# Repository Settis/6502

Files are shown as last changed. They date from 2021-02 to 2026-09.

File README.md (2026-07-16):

This was started as a self-educational project.
To understand how computer works I decided to create one.
The main rule here is that I should understand each bit, each connection.
I try to build it from scratch as much as possible.

I've started with a 6502 compatible CPU in Logisim [avaialbe here](/logisim/README.md).

Currently, I'm trying to build the real one around 65c816 CPU. 
As an example of how it looks you can see it working with three character displays running Wozmon:
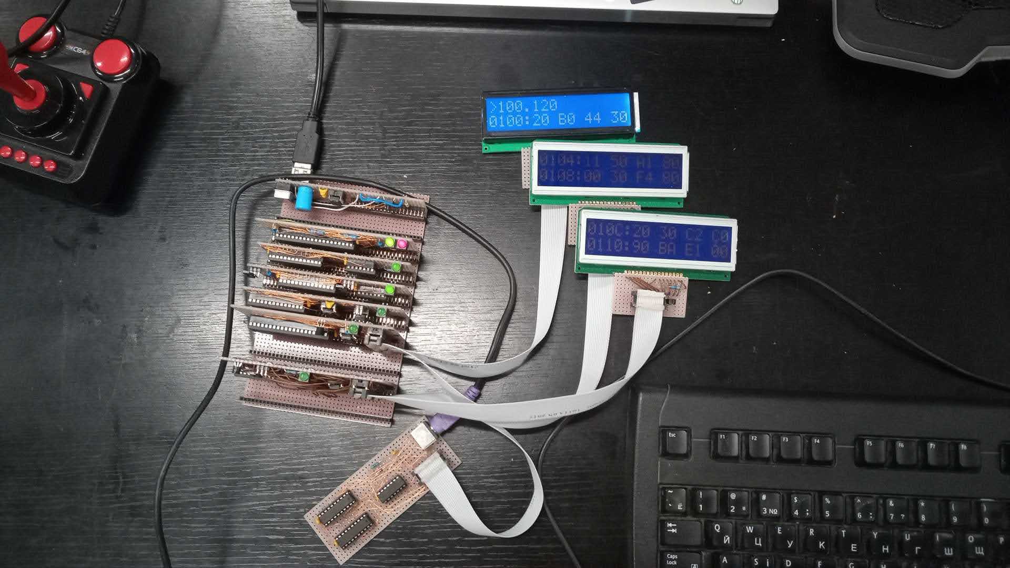
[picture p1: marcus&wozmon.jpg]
photo of 6502 computer running Wozmon


Finally I'm able to connect all peripherals at once:
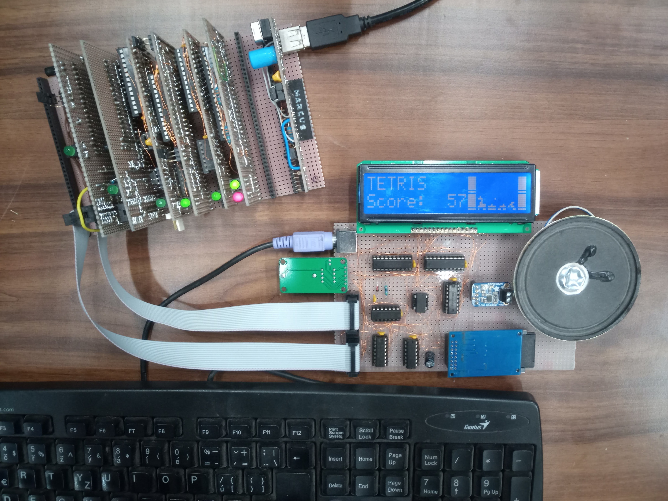
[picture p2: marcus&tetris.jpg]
photo of 6502 computer running Tetris


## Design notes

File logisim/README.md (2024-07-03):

This computer has a tty and graphical display. 
You can see how "comp.circ" looks like opened in Logisim:
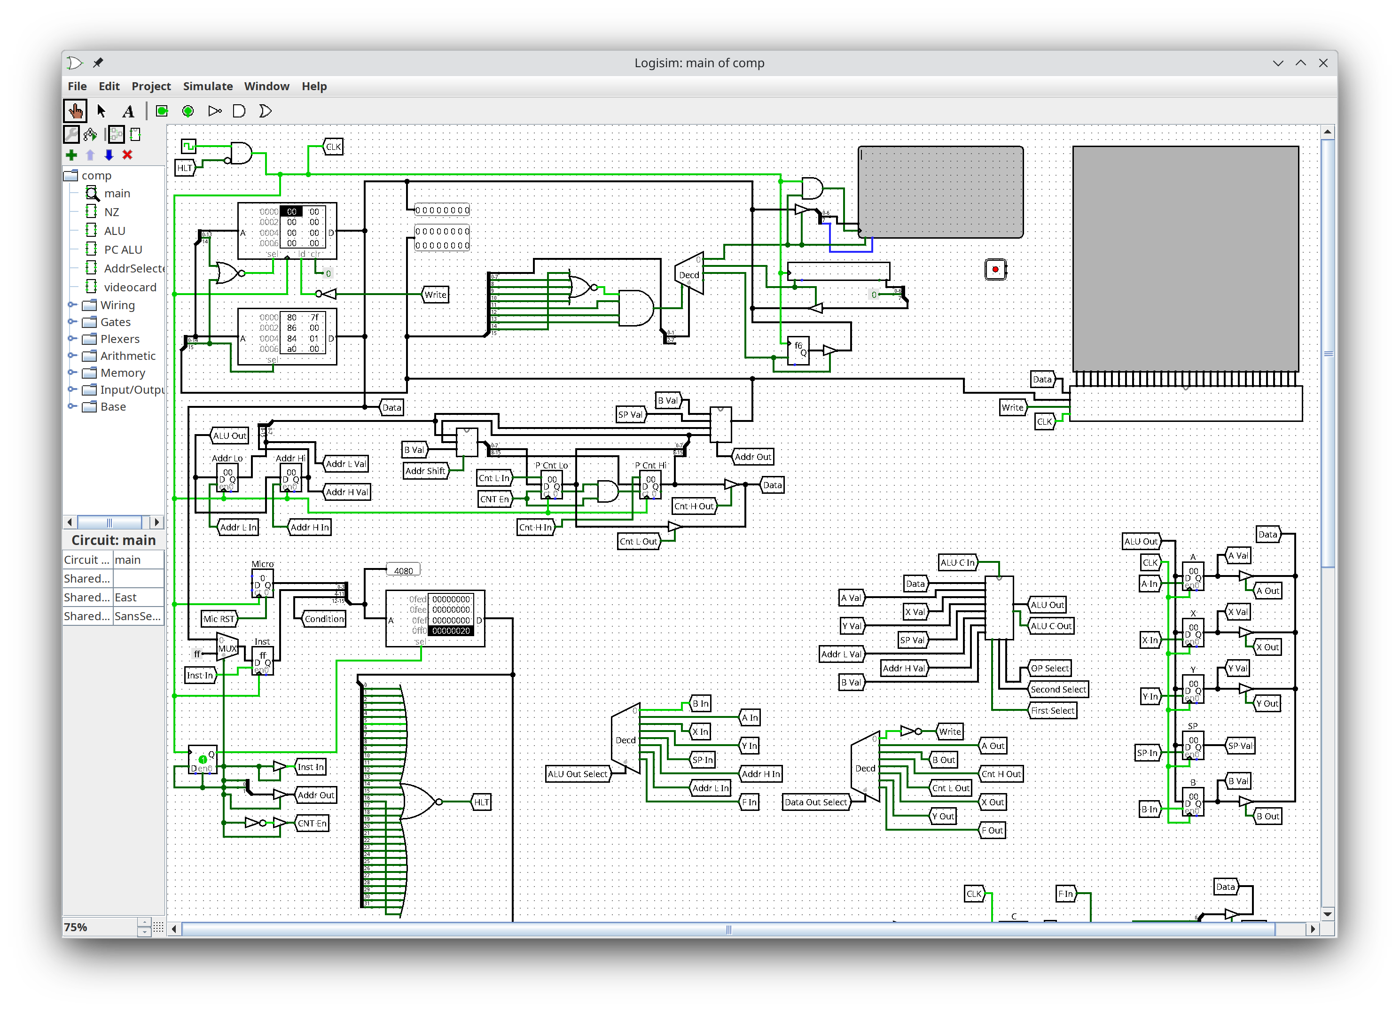
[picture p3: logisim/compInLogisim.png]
Logisim circuit


The microcode for the CPU was generated from "tools/microcodeSpec.yaml" by "tools/microcodeGen.py".

PNG images were converted by "tools/imageConvert.py".

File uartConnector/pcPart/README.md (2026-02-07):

# Communication with 6502 via UART
Happy coding!

## Local build & install
### Build package
> python3 -m pip install --upgrade build
> 
> python3 -m build
### Install package
> pip install 6502arch_uart-0.0.2-py3-none-any.whl

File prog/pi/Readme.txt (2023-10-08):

GPT предложил выводить бинарник при помощи `hexdump -v -e '/1 "%d "'`
Таким образом он выведет: 3 1 4 1 5 9 2 ...

```
const N = 1000;
const LEN = Math.floor((10 * N) / 3) + 1;

const a = Array(LEN);
let previousDigit = 2;
let nineCount = 0;

for (let i = 0; i < LEN; i++) {
  a[i] = 2;
}

let printed = 0;
while (printed < N) {
  // multiply each digit by 10
  // normalize representation
  //   each digit should be in range 0..2i, so carry extra rank to higher digit
  let carry = 0;
  for (let i = LEN - 1, numerator = (2 * LEN - 1); i > 0; i--, numerator -= 2) {
    const x = a[i] * 10 + carry;
    a[i] = x % numerator
    carry = Math.floor(x / numerator) * i;
  }

  // latest carry would be integer part of current number 
  //   and sequental digit of Pi
  const digitFromCarry = Math.floor(carry / 10);
  const nextDigit = carry % 10;

  // if current digit is 9, then we can't decide if we would have cascade carry
  if (nextDigit === 9) {
    nineCount++;
    continue;
  }

  // print previous digit, because now we knows if current digit is more than 10
  const currentDigit = previousDigit + digitFromCarry;
  process.stdout.write(currentDigit.toString());
  printed++;

  // if previous digit is followed by 9s, then print them 
  //   or 0s, if we have cascade carry
  for (let i = 0; i < nineCount; i++) {
    process.stdout.write((digitFromCarry === 0 ? 9 : 0).toString());
    printed++;
  }
  nineCount = 0;

  previousDigit = nextDigit;
}
```

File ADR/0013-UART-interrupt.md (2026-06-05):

# UART chip bug workaround

Status: accepted

## Context

Swapping DTR and RTS lines reveals another hardware bug.
When I setup that the data terminal is not ready, the terminal transfers bytes, and receive bytes.
Unfortunately, it stopped generating interrupts.

## Decision

Luckily, the DTR line is used as RTS and should stop the connected device from sending data.
Ideally, the other device should send no more than one byte after the RTS line is switched.
Even though the interrupt was not generated, chip status flags are updated accordingly.
Before allowing the other device sending data, 6502 should check flags and handle the received byte.

## Consequences

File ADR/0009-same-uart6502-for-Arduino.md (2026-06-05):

# Using the same uart6502 script for Arduino

Status: accepted

## Context
Historically, I started with an Arduino board connected to the bus.
The board emulates missing devices.
Then it was used for step-by-step debugging.
Unfortunately, it was too slow for PS2 keyboard and I stopped using it.

Currently, 6502 runs the UART monitor and executes commands from the laptop.
For communication I’ve created yet another Python script with it's own protocol and command line arguments.

So I have two UART connected devices: 6502 uart monitor and Arduino.
And two Python scripts accordingly.

## Decision
Extend the currently used uart6502 to work with debug commands.
So I can use the same tool and the same protocol across all devices.

## Consequences
Not all commands can be supported on both devices.
So far, I'll try to be careful.
But in case of heavily using both devices I have to change the protocol to indicate that some commands are not supported.
Or extend it with the command that reports the device type.

The UART monitor and Arduino react to the UART connection differently.
See ADR-0010.

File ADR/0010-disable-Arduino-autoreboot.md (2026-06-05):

# Disable Arduino autoreboot

Status: accepted

## Context
By default the Arduino board reboots each time the laptop establishes a connection to it.
It's useful for access Arduino bootloader and updating the firmware.

The UART monitor expects a connection per command.

When uart6502 connects to the Arduino, it reboots.
The whole Arduino is unrechible for some time, and some bytes sended via UART are lost.
Arduino reboot sequence changnes levels on GPIO, which cause some unpredictable 6502 reaction, line another clock cycle, memory write, etc.

## Decision
Restrict Arduino reboot by adding a capacitor between RST and GND.
The capacitor smooths out short reboot pulses during UART connection.
But a manual (button-press) reboot is long enough to discharge the capacitor.

The capacitor should be added to the display shield.
It would prevent reboots during debugging.
But I can easily disconnect the shield with the capacitor in case of updating the Arduino firmware.

## Conseqences

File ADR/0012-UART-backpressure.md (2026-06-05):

# UART chip flow control lines changes

Status: accepted

## Context

According to the specs, the RTS line from the W65C51 should be connected to the CTS line on another device.
Unfortunately, there is a bug in W65C51, and while the RTS line is activated, the chip stops sending data to the device.

## Decision

Use the DTR line on W65C51 instead of RTS.
Though the line is designed for other purposes, I can control it independently.
And, luckily, changing the signal on the line doesn't affect data sent from W65C51.

## Consequnces

It may be confusing that now DTR and RTS are swapped physically, but not in the code.
In order to change what should be RTS according to the specs, the 6502 code would work with DTR instead.

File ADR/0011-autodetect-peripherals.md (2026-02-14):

# Peripherals board should be autodetected

Status: accepted

## Context
Current FORTH implementation initialize display.
Before sending a command to display it checks its busy state.

Most often I want to connect to 6502 via UART only wihtout display, keyboard, etc.
See ADR-0000.
But without peritherals connected, FORTH stuck infinitly waiting for display to answer.

## Decision
Create an ability to detect if the peritheral board is connected.

Connect P2 and P3 pins together on port B.
They are not used in the peripheral board.
6502 can write signal to P2 and read it back via P3, detecting the board.

## Conseqences

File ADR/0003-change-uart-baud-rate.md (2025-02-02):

# Increase uart baud rate

Status: accepted

## Context
I'm using 9600 baud rate for connecting to the 6502.
I've found that it is a kind of standard baud rate that guarantees a stable connection.
Recently I started sending and receiving a lot of data, so the low baud rate slows things down.

## Decision
Rise the baud rate up to 115200.
Hoping that it will increase my speed up to 12 times without introducing transfer errors due to short connecting wires.

## Consequences

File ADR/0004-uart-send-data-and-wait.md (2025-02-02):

# UART monitor should send data with the right timing

Status: accepted

## Context
UART chip W65C51 has a bug in interrupt logic.
I can't detect by interrupt when the byte is sent out.
Luckily interrupt of incoming byte works.

To make the UART monitor simple I decided to send only one byte at once.
If 6502 logically has to send several bytes, like when I read memory, it sends only one byte and waits for ack from a laptop.
I do not have to care about timing, but this is slow.

## Decision
I'll change the protocol, so 6502 can send subsequent bytes independently without requesting information byte-by-byte.

## Consequences

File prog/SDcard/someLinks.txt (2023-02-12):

http://elm-chan.org/docs/mmc/mmc_e.html
https://electronics.stackexchange.com/questions/77417/what-is-the-correct-command-sequence-for-microsd-card-initialization-in-spi

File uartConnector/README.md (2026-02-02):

# Protocol

## Ping
Command number: **1**

PC sends to 6502 the command ID and a random number from 1 to 200.
The 6502 must return the number incremented by 1.

*Example:*
> **PC -> 6502:** 0x01 0x0A
> 
> **6502 -> PC:** 0x0B

## Write data
Command number: **2**

PC sends to 6502 the command ID, starting address (2 bytes, little endian), length of data (1 byte), and the actual data.
The 6502 will return CRC8 (0x07) checksum of the data.

*Example:*

> **PC -> 6502:** 0x02 0x02 0x05 0x09 "123456789"
>
> **6502 -> PC:** 0xF4

## Read data
Command number: 3

PC sends to 6502 the command ID, starting address (2 bytes, little endian), length of data (1 byte).
The 6502 will return the data and CRC8 sum.

*Example:*

> **PC -> 6502:** 0x3 0x02 0x05 0x09
> 
> **6502 -> PC:** "123456789" 0xF4

## Run subroutine
Command number: 4

PC sends to 6502 the command ID and subroutine address (2 bytes, little endian).
When 6502 is ended the subroutine it sends the command ID back.

*Example:*

> **PC -> 6502:** 0x4 0x00 0x03
> 
> **6502 -> PC:** 0x4

## Step debugger
Command number: 5

PC sends to 6502 the command ID, mode, address, [data byte].

Stop by:
- address r/w
- read any
- write any
- read byte
- write byte
- report each step
- quiet

mode:
-  0x01 - any action to address
-  0x02 - check r/w direction
-  0x04 - match r/w pin
-  0x08 - check data byte
-  0x10 - quiet or send steps

The end byte is WDM opcode 0x42. It's reserved for future microporcessors and won't be used in assembly (I hope).

It should be zero terminated.

Output is the packets of 4 bytes, zero terminated
    (0x80 | r/w, byte, addr), {Opcode, addr, args size, [args], (0x80 | r/w, byte, addr)}, 0x00
    flags byte:
        0x80 - data is presented
        0x01 - r/w
        0x02 - vpa
        0x04 - vda
    data byte,
    addr (lo, hi)

*Example:*

> **PC -> 6502:** 0x5 0x1 0x00 0x03
> 
> **6502 -> PC:** 0

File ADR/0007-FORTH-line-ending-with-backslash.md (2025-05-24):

# FORTH input line ending with backslash

Status: accepted

## Context

User input is collected into the line input buffer.
At first glance, the line ends with 0x00, like a C-style string.
But one character with zero inside is a registered FORTH word, so ENCLOSE should find it at the end of the line.
The ENCLOSE extracts words between provided delimiters (usually space).
And for the "end of line" recognition, I have to wrap the zero character with spaces, or implement ENCLOSE in a way it can recognize zero.

## Decision

ENCLOSE should do simple and straightforward work: extract the word between delimiters.
So "DROP<0>" should be converted to "DROP <0> ".
FORTH has the '\' symbol, which specifies a comment till the end of the line.
Taking this into account, I can replace <0> with '\'.
For compilation and interpretation it doesn't matter if this backslash is an end-of-line marker or introduces a comment that should be ignored.
In both cases FORTH can move to the next line.

## Consequences

It will be impossible to print the line having a comment.
For example if a program is executed from a file and an error occurs, for debug purposes it will be good to print the whole line containing the error.
If this line has a comment it will be printed without it.

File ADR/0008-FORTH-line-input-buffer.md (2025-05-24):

# FORTH reusage of line input buffer for files

Status: accepted

## Context

FORTH-83 uses a line input buffer to collect a line from user input.
FORTH files have fixed line length and a disk block contains an integer number of lines.
Lines read from a file can be directly executed from the block.
I want to use a modern text file format with lines ending with '\n'.
Those lines can't be executed from the memory-mapped block.

## Decision

Reuse the line input buffer for working with files too.
Before execution a line will be copied from the disk block into the buffer.
In case the line starts in one block but ends in another, it will be correctly collected in the buffer.

## Consequences

It will be impossible to have something after the "import <file>" command because the import execution overwrites this line buffer.

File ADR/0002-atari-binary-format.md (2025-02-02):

# Use atari binary format

Status: accepted

## Context

Because DASM does not support W65C816 CPU I switched to ca65.
In DASM I used the default output format where ROM data were prefixed with the origin address.
ca65 does not have such an output option.

I can either: 
- replicate DASM output format with cc65 toolchain
- use simple raw ROM format without any headers
- use Atari format provided by cc65 toolchain

## Decision
Using Atari format.
It's supported in cc65 out of the box.
I don't have to invent anything else to keep tracking where the origin is.

## Consequences
I have to rewrite my toolchain for program loading.

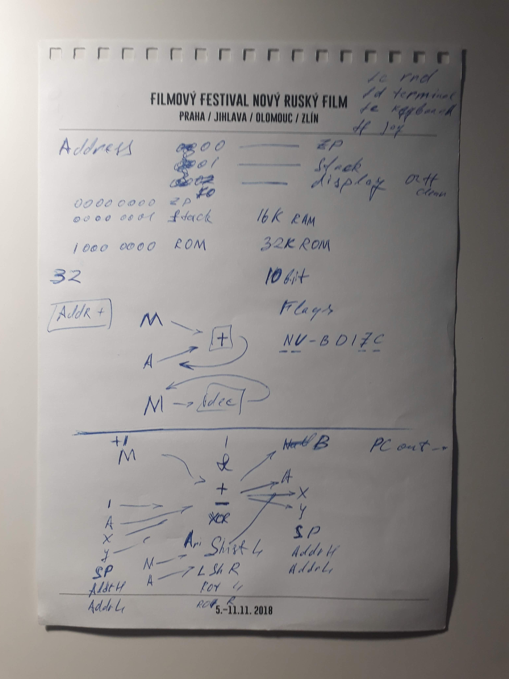
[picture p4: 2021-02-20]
logisim/designRecords/addr_alu.jpg

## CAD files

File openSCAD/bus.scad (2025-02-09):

include <common.scad>

bus_pcb = pcb_cut();

module bus() {    
    pcb(bus_pcb);
    for(i = [1 : 6 : 60]) {
        pcb_grid(bus_pcb, i, 0)
        pin_socket_row(board_width_pins);
    }
    pcb_grid(bus_pcb, 59, 36)
    usb_connector();
}

bus();

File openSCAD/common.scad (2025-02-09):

include <NopSCADlib-21.33.0/lib.scad>
include <NopSCADlib-21.33.0/vitamins/dip.scad>

//$fa = 1;
//$fs = 0.4;

hols_step = inch(0.1);
board_width_pins = 39;

function pcb_cut(length_pins=62) = ["UP830EP", "Perfboard 160x100mm", length_pins*hols_step, 100, 1.6, 0, 2.3, 0, "green", true, [], [], [], [hols_step*0.5, hols_step*0.75]];

module chip(legs, socketed = false, w = inch(0.3)) {
    translate([w/2, -hols_step*((legs/2-1)/2), 0])
        pdip(legs, "", socketed, w);
}

module socket(legs, w = inch(0.3)) {
    translate([w/2, -hols_step*((legs/2-1)/2), 0])
        dil_socket(legs/2, w);
}

module pin_header_row(count, right_angle = false) {
    rotate([0, 0, 90])
    translate([hols_step * (count-1)/2, 0, 0])
        pin_header(pin_headers[0], count, 1, right_angle = false);
}

module bended_pin_header_row(count) {
    rotate([0, 0, 90])
    translate([hols_step * (count-1)/2, hols_step/2, hols_step*2])
        rotate([90, 0, 0]) difference() {
            pin_header(pin_headers[0], count, 1, right_angle = true);
            translate([0, -hols_step*3.8, hols_step*0.5])
            cube([hols_step*count, hols_step*1.5, hols_step], center = true);
        }
}

module pin_socket_row(count) {
    rotate([0, 0, 90])
    translate([hols_step * (count-1)/2, 0, 0])
        pin_socket(pin_headers[0], count, 1);
}

module res_small() {
    translate([hols_step, 0, 0])
        ax_res(ax_resistors[0], [1000, 47000, 8200][0], 5);
}

module res() {
    translate([hols_step*1.5, 0, 0])
        ax_res(ax_resistors[1], [1000, 47000, 8200][1], 5);
}

module res_big() {
    translate([hols_step*2.5, 0, 0])
        ax_res(ax_resistors[2], [1000, 47000, 8200][2], 5);
}

module usb_connector() {
    translate([hols_step*2.5,-hols_step*1.5,0])
        molex_usb_Ax1(cutout = false);
}

module jumper() {
    eps = 0.001;
    translate([-hols_step/2, 0, hols_step*2])
    rotate([-90, 0, 90])
    // the jumber in zero coords
    translate([-2.5/2, -2.5/2, 0])
    color(grey(40))
    difference() {
        union() {
            difference() {
                union() {
                    translate([0, (2.5-0.7)/2, 0]) cube([5.1, 0.7, 13.6]);
                    cube([5.1, 2.5, 5.97]);
                    translate([0, (2.5-1.2)/2, 13.6-1.2]) cube([5.1, 1.2, 1.2]);
                }
                translate([-eps, -eps, 5.97-1.5]) cube([5.1+2*eps, 2.5+2*eps, 1]);
            }
            translate([0.25, 0.25, 5.97-1.5-eps]) cube([5.1-0.5, 2, 1+2*eps]);
        }
        translate([(5.1-1)/2, -eps, 5.97-2]) cube([1, 3, 5]);
    }
}

module led_up() {
    rotate([-90,0,-90])
    translate([hols_step/2, -3, 5.1])
    // the led
    union() {
    difference() {
    union() {
        translate([0,0,-4])
        led(LED5mm, "green");
        color(grey(20))
        translate([0,0,-9.1/2])
        cube([6,6,9.1], center=true);
    }
        translate([0, -5, -11])
        rotate([45, 0, 0])
        cube(13, center=true);
    }
    color("silver")
        for(side = [-1, 1])
            translate([hols_step/2*side, 4.5, -5.1])
            cube([0.5, 3.5, 0.5], center=true);
    }
}

module cap() {
    i = 0;
    disc = rd_discs[i];
            pitch = rd_disc_pitch(disc);
            dx = round(pitch.x / inch(0.1)) * inch(0.1);
            dy = round(pitch.y / inch(0.1)) * inch(0.1);
            
            translate([0, hols_step, 0])
            rotate(90 - atan2(dy, dx))
                rd_disc(disc, pitch = norm([dy, dx]), z = 0.5, value = ["10nF", "470V", "1nF Y2"][i]);
}

module transistor() {
    translate([hols_step, 0, 0])
    rd_transistor(rd_transistors[1], "", lead_positions = inch(0.1) * [[-1, 0], [0, -sign(0)], [1, 0]]);
}

module reposition_board(length_pins) {
    translate([hols_step*2.6, -hols_step*board_width_pins/2 + hols_step/2, hols_step*0.2 + hols_step*length_pins/2])
    rotate([0, -90, 0])
        children(0);
}

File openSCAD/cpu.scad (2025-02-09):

include <common.scad>

module cpu_board() {
    pcb = pcb_cut(17);
    pcb(pcb);
    
    pcb_grid(pcb, 3, 0)
    bended_pin_header_row(board_width_pins);
    
    pcb_grid(pcb, 6, 34)
    chip(40, true, w=hols_step*6);
    
    pcb_grid(pcb, 10, 14)
    rotate(-90)
    cap();
    
    pcb_grid(pcb, 13, 34)
    res();
    
    pcb_grid(pcb, 5, 36)
    res_big();
    
    pcb_grid(pcb, 15, 19)
    rotate(90)
    res_big();
    
    pcb_grid(pcb, 15, 12)
    rotate(90)
    res_big();
    
    pcb_grid(pcb, 15, 2)
    led_up();
    
    pcb_grid(pcb, 15, 5)
    led_up();
    
    pcb_grid(pcb, 9, 2)
    res();
    
    pcb_grid(pcb, 9, 5)
    res();
    
    pcb_grid(pcb, 8, 8)
    res_big();
}

module cpu() {
    reposition_board(17)
    cpu_board();
}

cpu();

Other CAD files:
openSCAD/marcus.scad
openSCAD/ram.scad
openSCAD/resetAndClock.scad
openSCAD/rom.scad
openSCAD/uart.scad
openSCAD/via1.scad
openSCAD/via2.scad

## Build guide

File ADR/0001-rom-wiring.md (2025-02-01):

# Allow 6502 to write ROM independently

Status: accepted

## Context
For updating the ROM I use Arduino board.
Arduino can control the clock and disconnect the CPU from the bus.
This allows to update the ROM content without taking the chip out of the board.
But in any case, I have to manipulate the hardware: take out the module with the clock generator and insert the Arduino connector.

For extra writing protection, EEPROM's WE line is not connected to WE line controlled by CPU.
EEPROM writing happens only during the "write" signal on WE as well as OE is disabled.
Since most of the time I need only read the OE pin is controlled by jumper.

There is software data protection in my EEPROM.
Unfortunately, I can't use it because unlocking sequence requires several writings to particular addresses.
Not all EEPROM's addresses are available to the CPU, because the A14 pin is controlled by jumper.
So I can work with software data protection in lower bank only.

## Decision
Connect EEPROM's WE line to CPU controlled WE line.
This allows to update EEPROM's content without connecting Arduino into the bus.
Meanwhile, OE pin will be controlled by jumber.
On one hand it's hardware data protection, on another hand CPU can't read bytes from the EEPROM, so it can't detect when the writing cycle will be over.
I have to implement writing logic based on timeouts.

## Consequences

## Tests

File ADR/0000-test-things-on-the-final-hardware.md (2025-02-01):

# Test things as close to the final hardware as possible

Status: accepted

## Context

Sure thing I have to test the hardware and software.

When I started the project I put an Arduino into the bus and it was my in-circuit debugger.
On one hand, it was really useful allowing me to debug in step-by-step mode.
On the other hand, disconnecting the 6502 computer from Arduino to work on its own was painful.
Because Arduino pulled lines and initiated things, steps that I didn't replicate in my hardware.

Another example is my experiments with FORTH.
I started them in an emulator, but because the emulator didn't support timers I decided to switch it to the hardware.
Unfortunately, emulator's 65C51 worked correctly, but my hardware has a bug.
So I lost some time debugging this weird behavior.

## Decision

Do everything in the real hardware.
Even if it's hard to debug, I better should invent tools for debugging and testing with my hardware.

Create the initial ADR with this for not to forget.

Recently I started development with 65C816 features, that are not compatible with 6502.
Since there are lack of 65C816 emulators it will be easy to keep things working on my hardware.

## Consequences

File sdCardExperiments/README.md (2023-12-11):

```
# sudo fdisk -lu rawDisk
# sudo mount -o offset=$((512*2048)),uid=1000,user ./rawDisk /mnt
# sudo losetup -o $((512*2048)) /dev/loop1 ./rawDisk
# sudo fsck -fv /dev/loop1
# sudo mkfs.vfat -s 2 -F 32 /dev/loop1

# sudo losetup -d /dev/loop1
```

What's on the disk:
```
# find .
.
./theFile.txt
./theLongFileName.txt
./folder
./folder/first.dat
./folder/second.dat
# cat theFile.txt 
some data here
# cat theLongFileName.txt 
another thing
```

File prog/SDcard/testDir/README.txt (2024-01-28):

There will be several files with different size.

Filenames in lowercase on purpose. This will create a VFAT name for each file, and the file table will not fit into one sector.

file 01 - 0x0000 -    0
file 02 - 0x0001 -    1
file 03 - 0x0010 -   16
// check page border
file 04 - 0x0100 -  256
file 05 - 0x00FF -  255
file 06 - 0x0101 -  257
// check sector border
file 07 - 0x0200 -  512
file 08 - 0x0201 -  513
file 09 - 0x01FF -  511
// check cluster border (8 sectors)
file 10 - 0x1000 - 4096
file 11 - 0x1001 - 4097
file 12 - 0x0FFF - 4065
// check a big file (bigger than 6502 can address)
file 13 - 100Kb

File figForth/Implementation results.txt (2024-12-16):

classic.asm where return stack implemented in software

my-Forth
RUN
Compile time:FF4C  653,560,000 ticks   100%
Dictionary:0120                        100%
Init time:075D      18,850,000 ticks   100%
Sort time:73A9     296,090,000 ticks   100%

hStack.asm where return stack is 6502 hardware stack
my-Forth
RUN
Compile time:F950  638,240,000 ticks    97.7%
Dictionary:0120                        100% 
Init time:0731      18,410,000 ticks    97.7%
Sort time:70D0     288,800,000 ticks    97.5%

hStackOptimized.asm where DOCOL & DOSEMICOL rewrited
Compile time:4585  177,970,000 ticks    27.2%
Dictionary:0120 
Init time:0201       5,130,000 ticks    27.2%
Sort time:1F0B      79,470,000 ticks    26.8%

nativeCalls.asm where JSR & RTS used insead of DOCOL and DOSEMICOL
                                     |from     | from
                                     |classic  | optimized
Compile time:2701   99,850,000 ticks    15.3%     56.1%
Dictionary:016B                        126%       
Init time:0129       2,970,000 ticks    15.8%     57.9%
Sort time:1329      49,050,000 ticks    16.7%     61.7%

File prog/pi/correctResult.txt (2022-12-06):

00000000  03 01 04 01 05 09 02 06  05 03 05 08 09 07 09 03  |................|
00000010  02 03 08 04 06 02 06 04  03 03 08 03 02 07 09 05  |................|
00000020  00 02 08 08 04 01 09 07  01 06 09 03 09 09 03 07  |................|
00000030  05 01 00 05 08 02 00 09  07 04 09 04 04 05 09 02  |................|
00000040  03 00 07 08 01 06 04 00  06 02 08 06 02 00 08 09  |................|
00000050  09 08 06 02 08 00 03 04  08 02 05 03 04 02 01 01  |................|
00000060  07 00 06 07 09 08 02 01  04 08 00 08 06 05 01 03  |................|
00000070  02 08 02 03 00 06 06 04  07 00 09 03 08 04 04 06  |................|
00000080  00 09 05 05 00 05 08 02  02 03 01 07 02 05 03 05  |................|
00000090  09 04 00 08 01 02 08 04  08 01 01 01 07 04 05 00  |................|
000000a0  02 08 04 01 00 02 07 00  01 09 03 08 05 02 01 01  |................|
000000b0  00 05 05 05 09 06 04 04  06 02 02 09 04 08 09 05  |................|
000000c0  04 09 03 00 03 08 01 09  06 04 04 02 08 08 01 00  |................|
000000d0  09 07 05 06 06 05 09 03  03 04 04 06 01 02 08 04  |................|
000000e0  07 05 06 04 08 02 03 03  07 08 06 07 08 03 01 06  |................|
000000f0  05 02 07 01 02 00 01 09  00 09 01 04 05 06 04 08  |................|

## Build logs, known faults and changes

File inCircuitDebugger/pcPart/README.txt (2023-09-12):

Use ramBased.py for everything

dependencies is pyserial

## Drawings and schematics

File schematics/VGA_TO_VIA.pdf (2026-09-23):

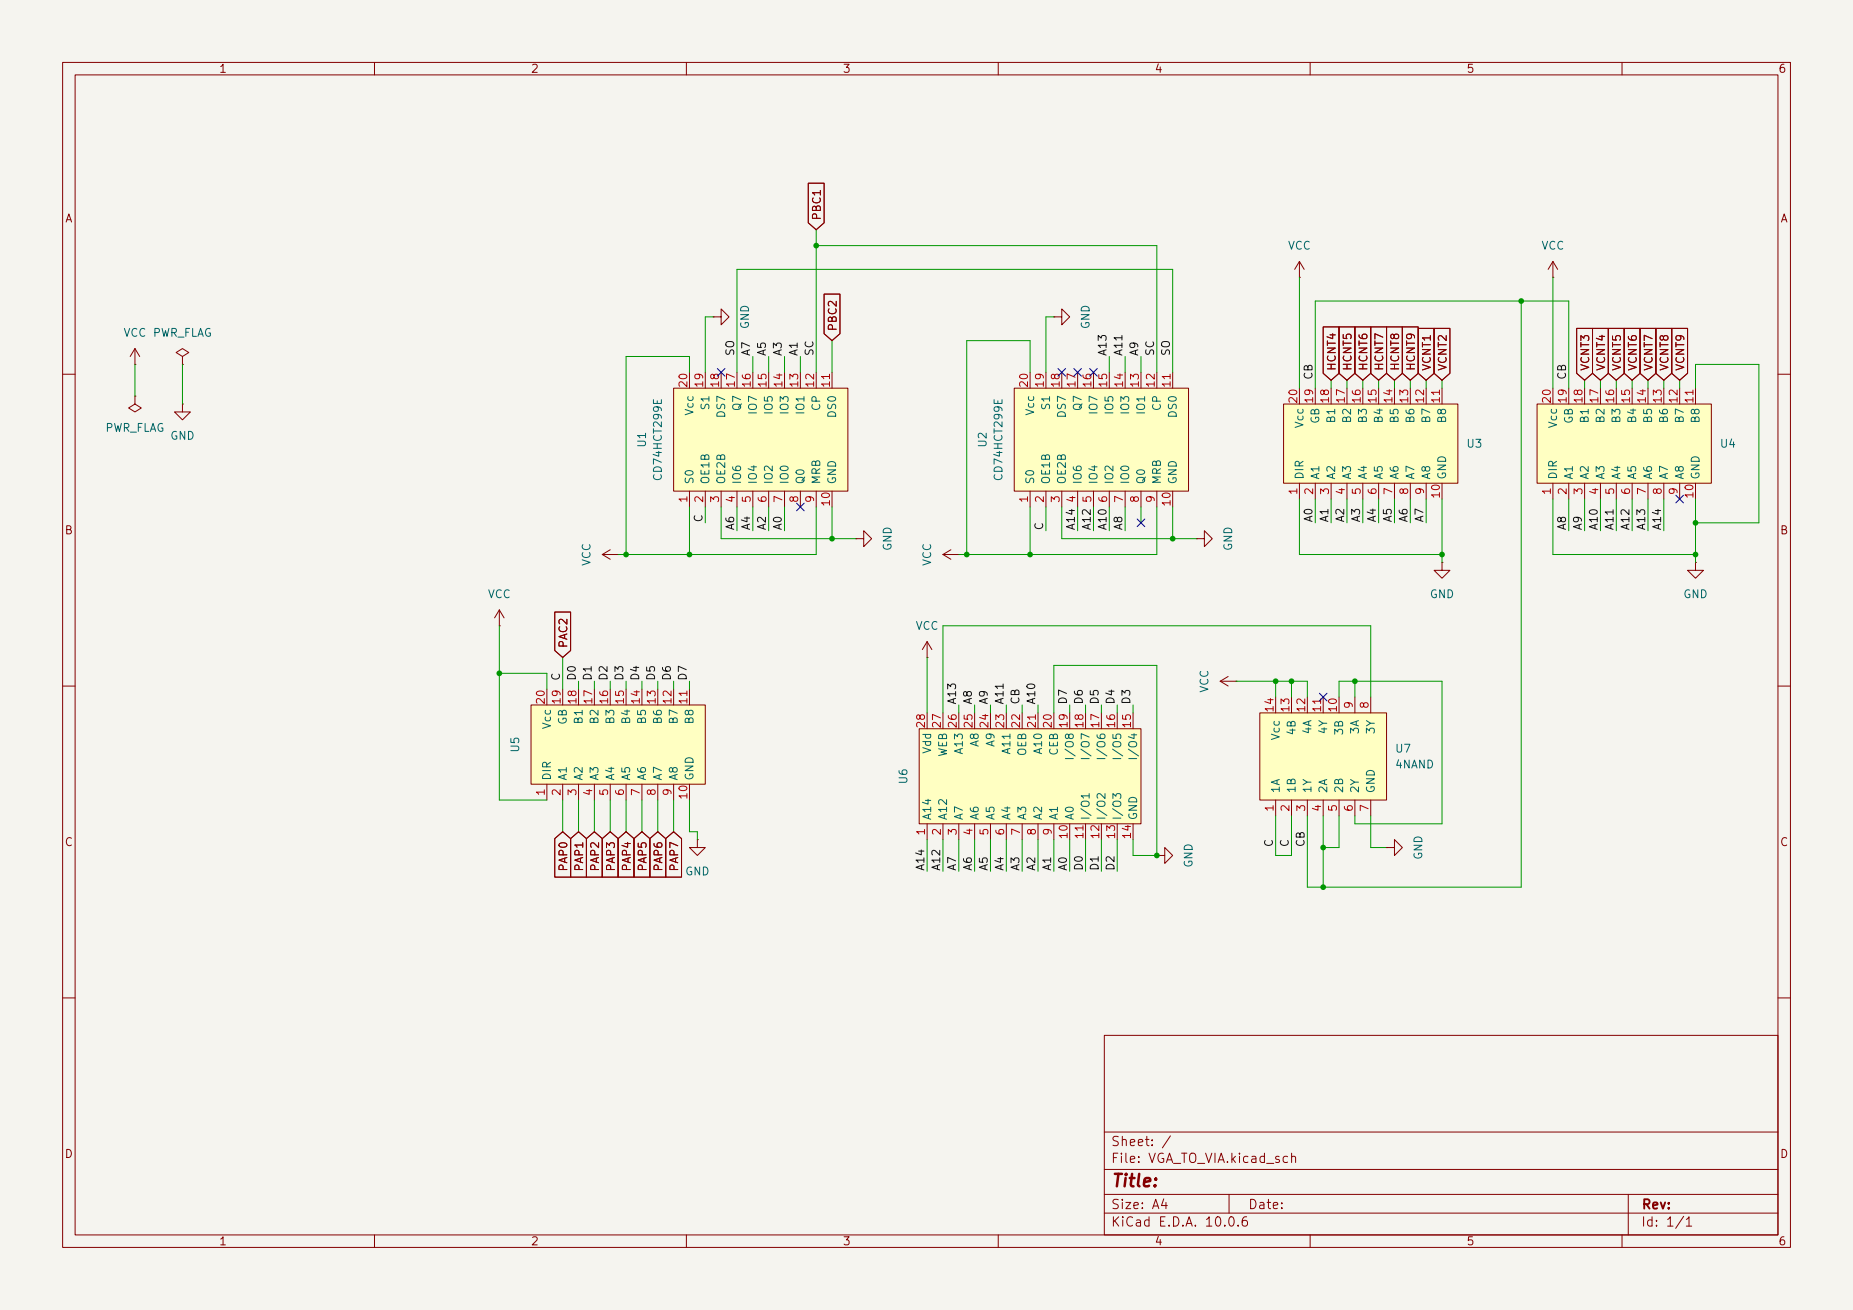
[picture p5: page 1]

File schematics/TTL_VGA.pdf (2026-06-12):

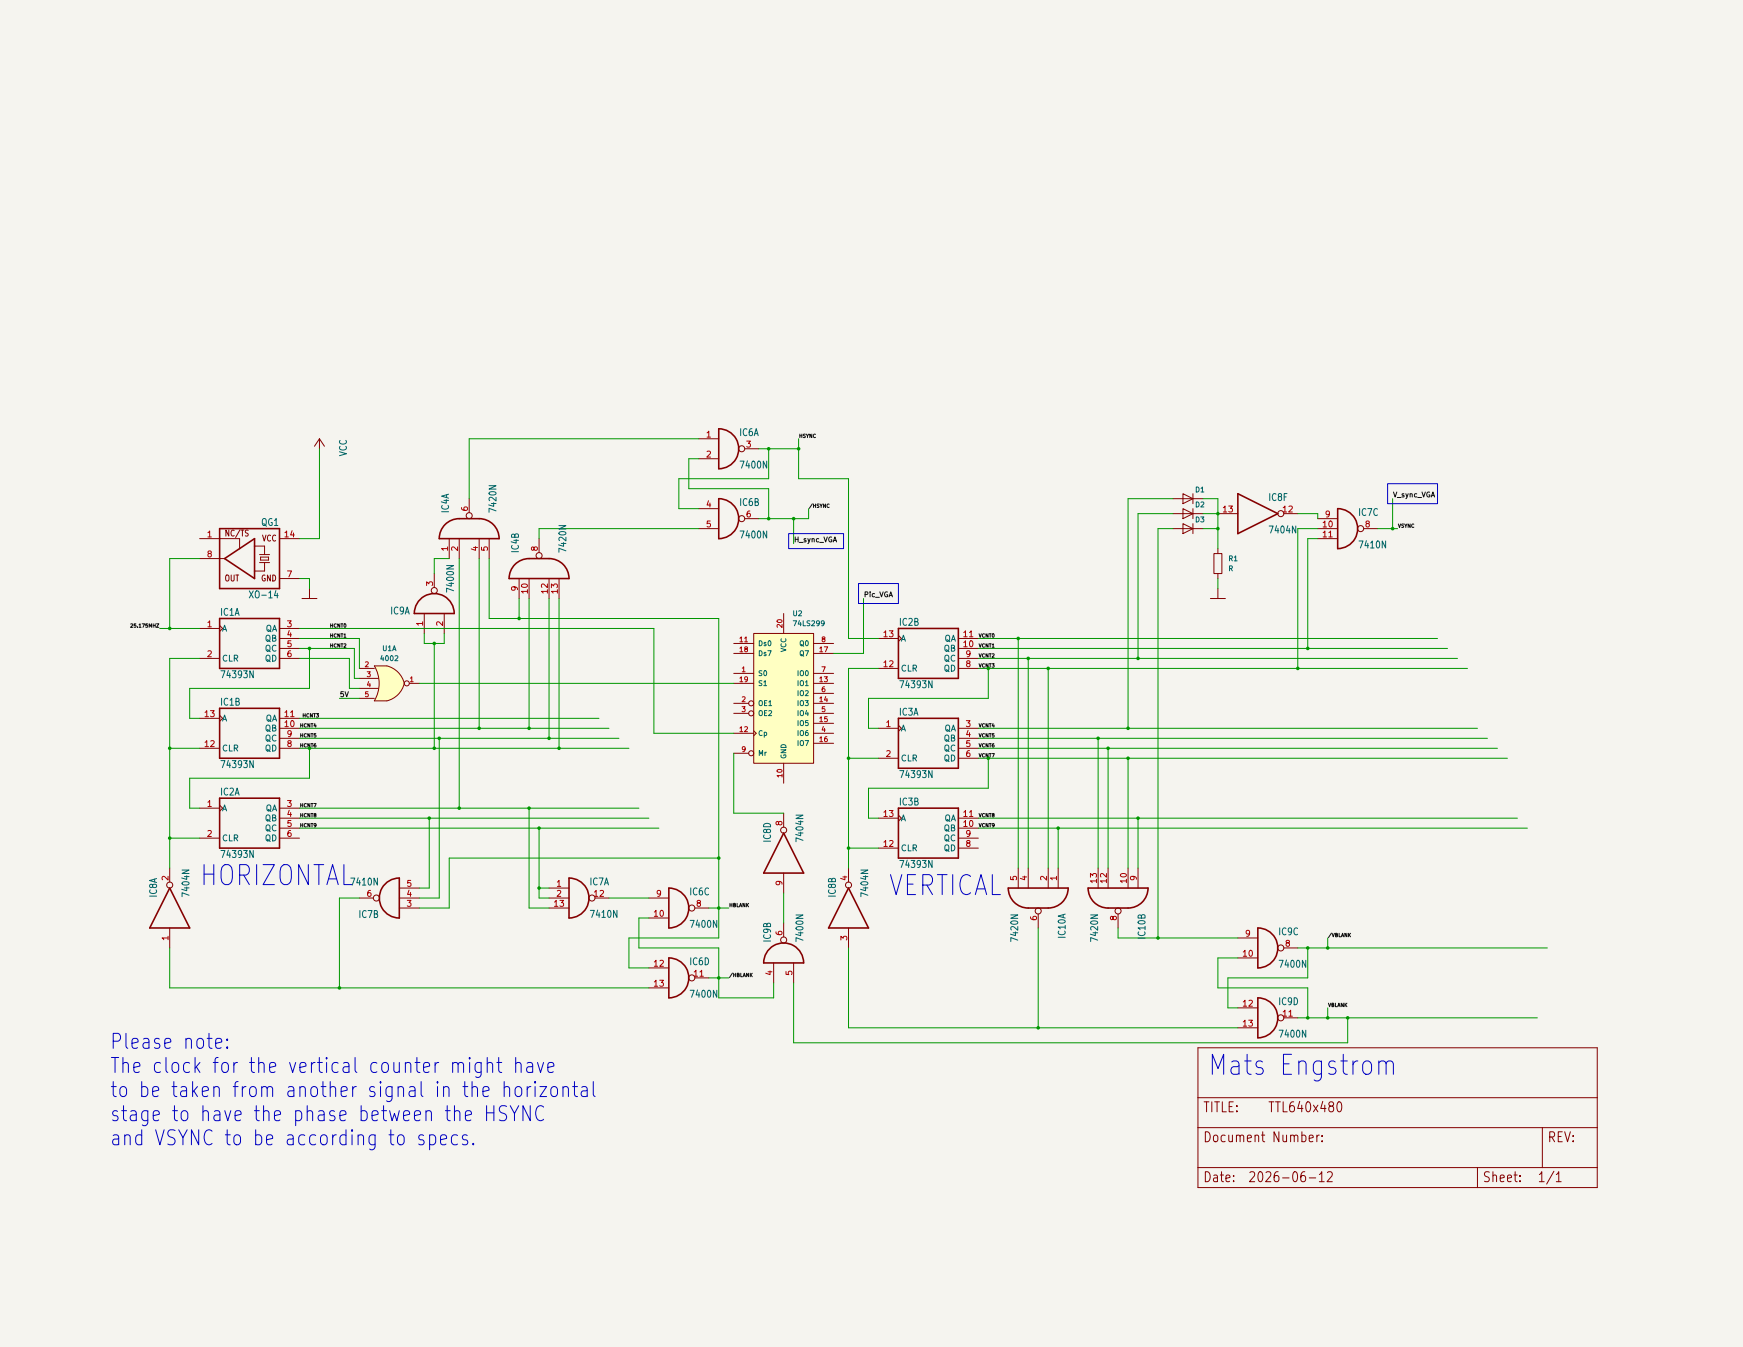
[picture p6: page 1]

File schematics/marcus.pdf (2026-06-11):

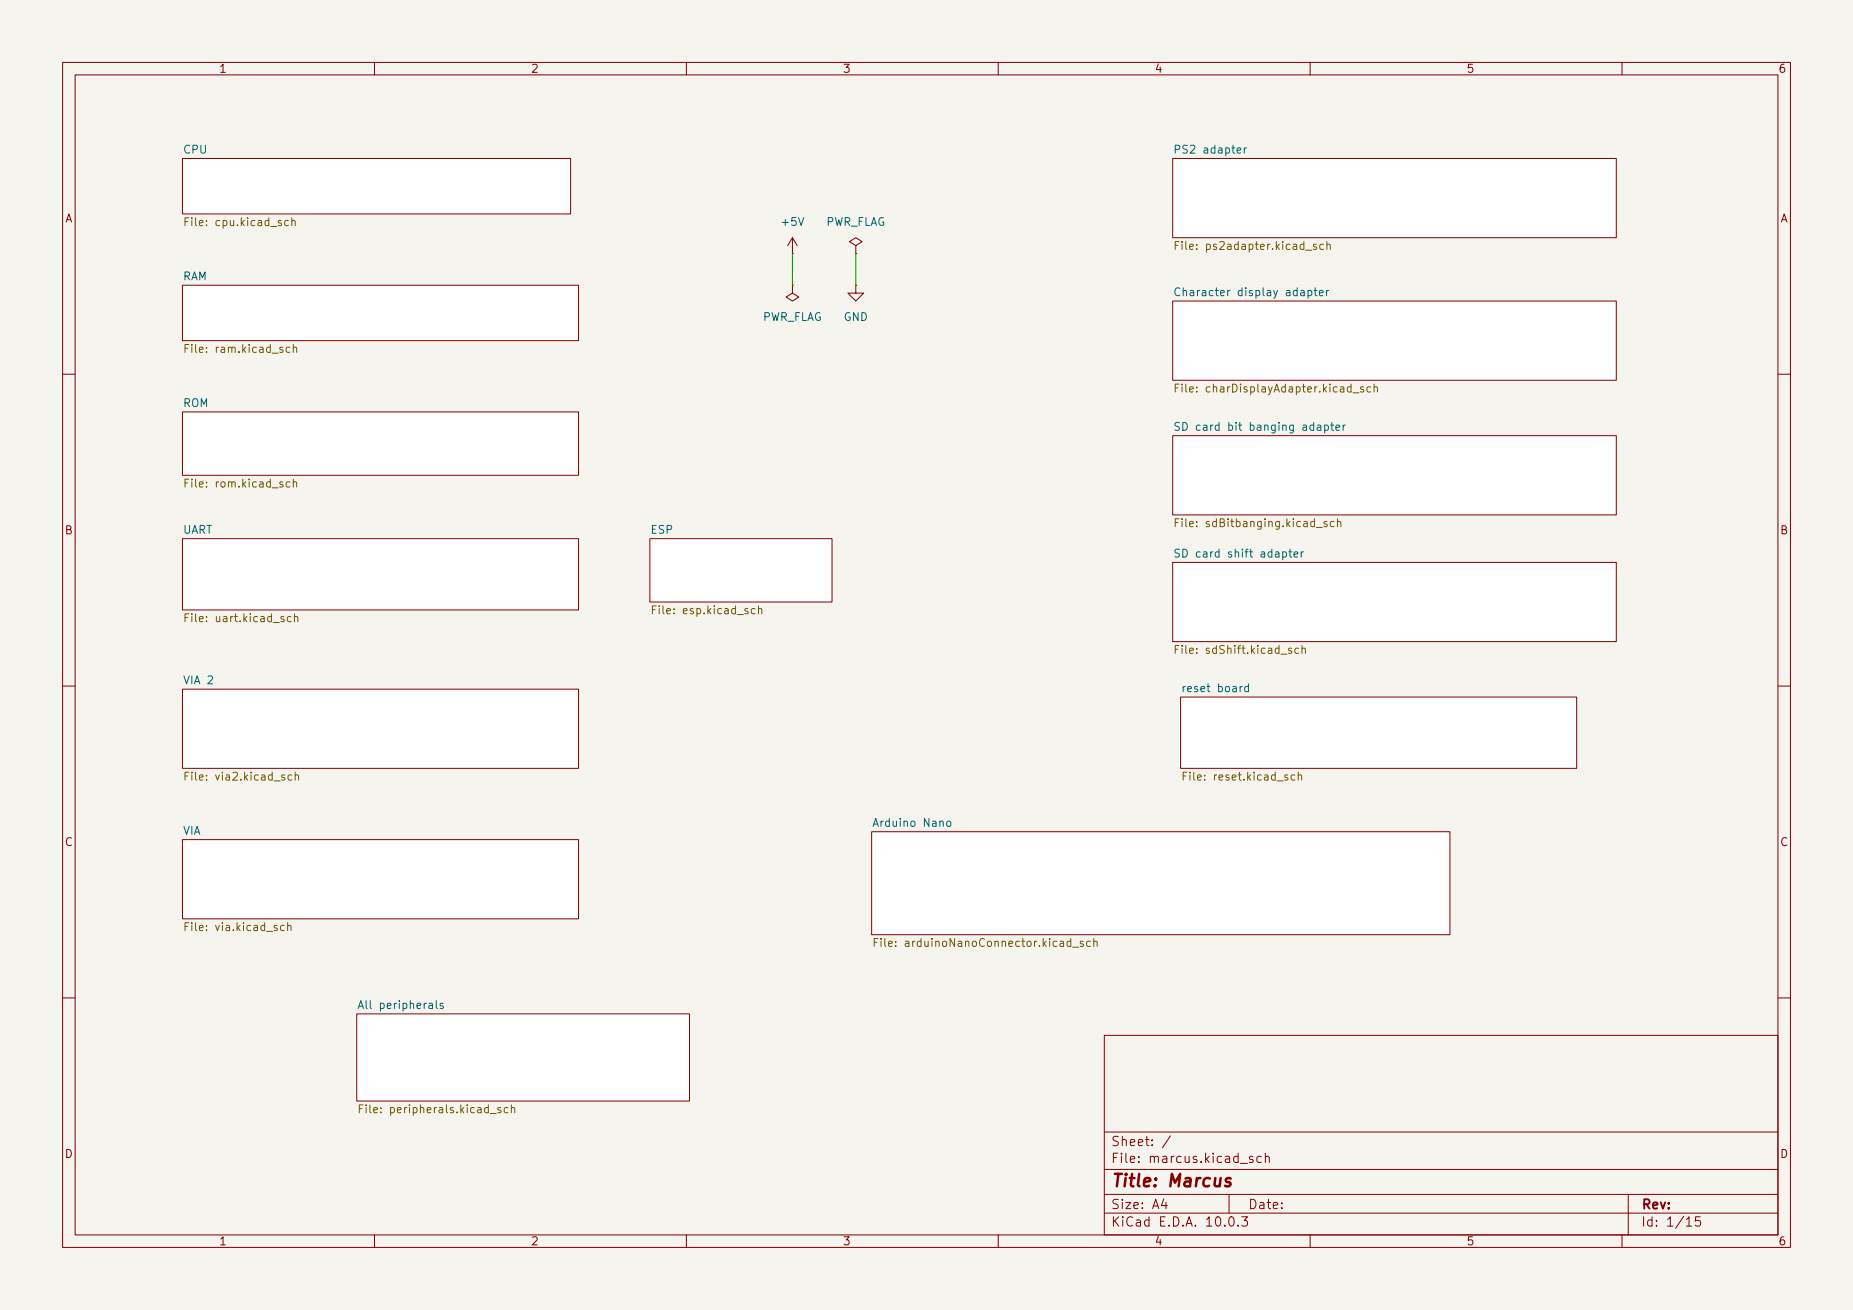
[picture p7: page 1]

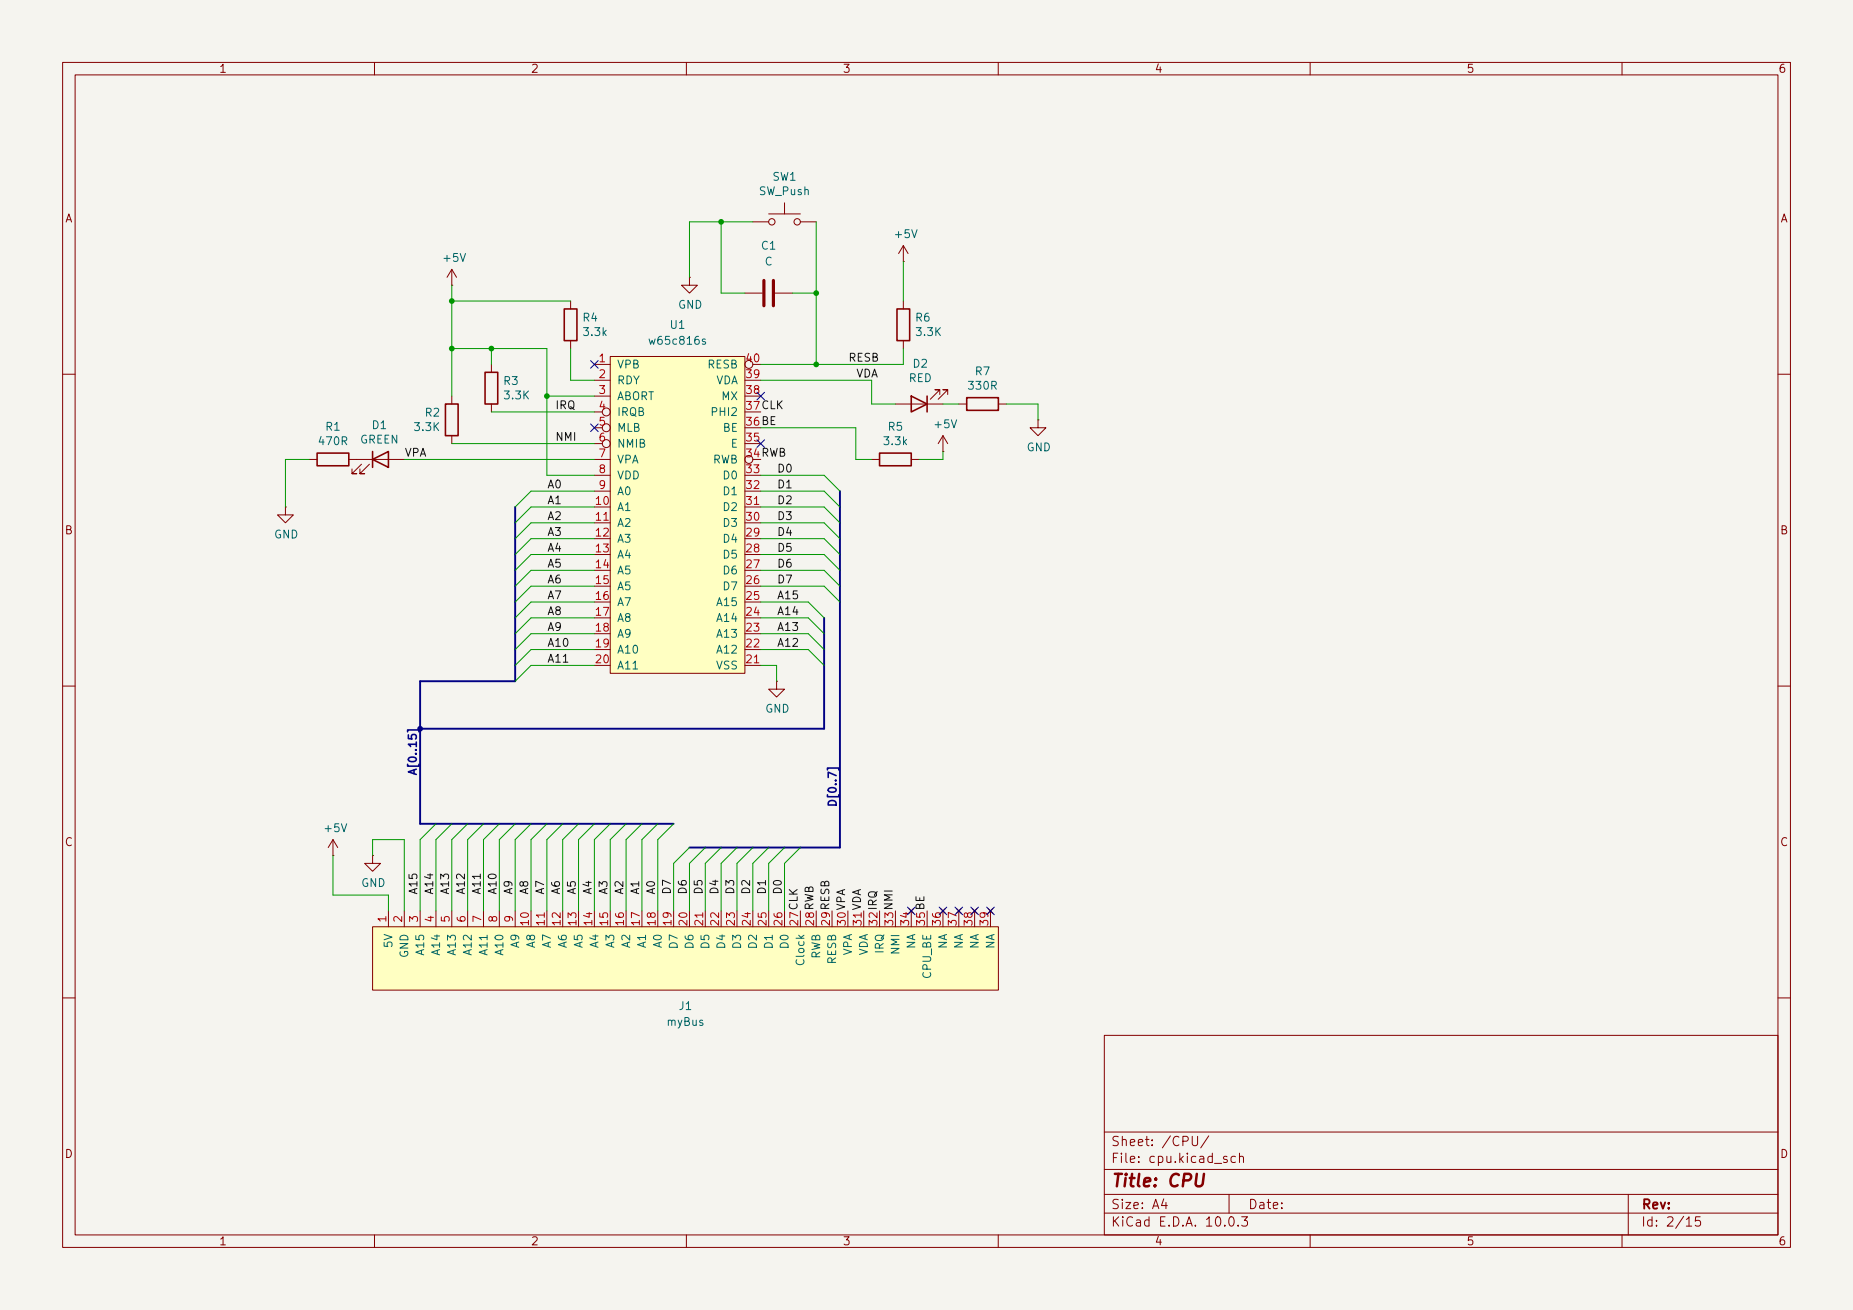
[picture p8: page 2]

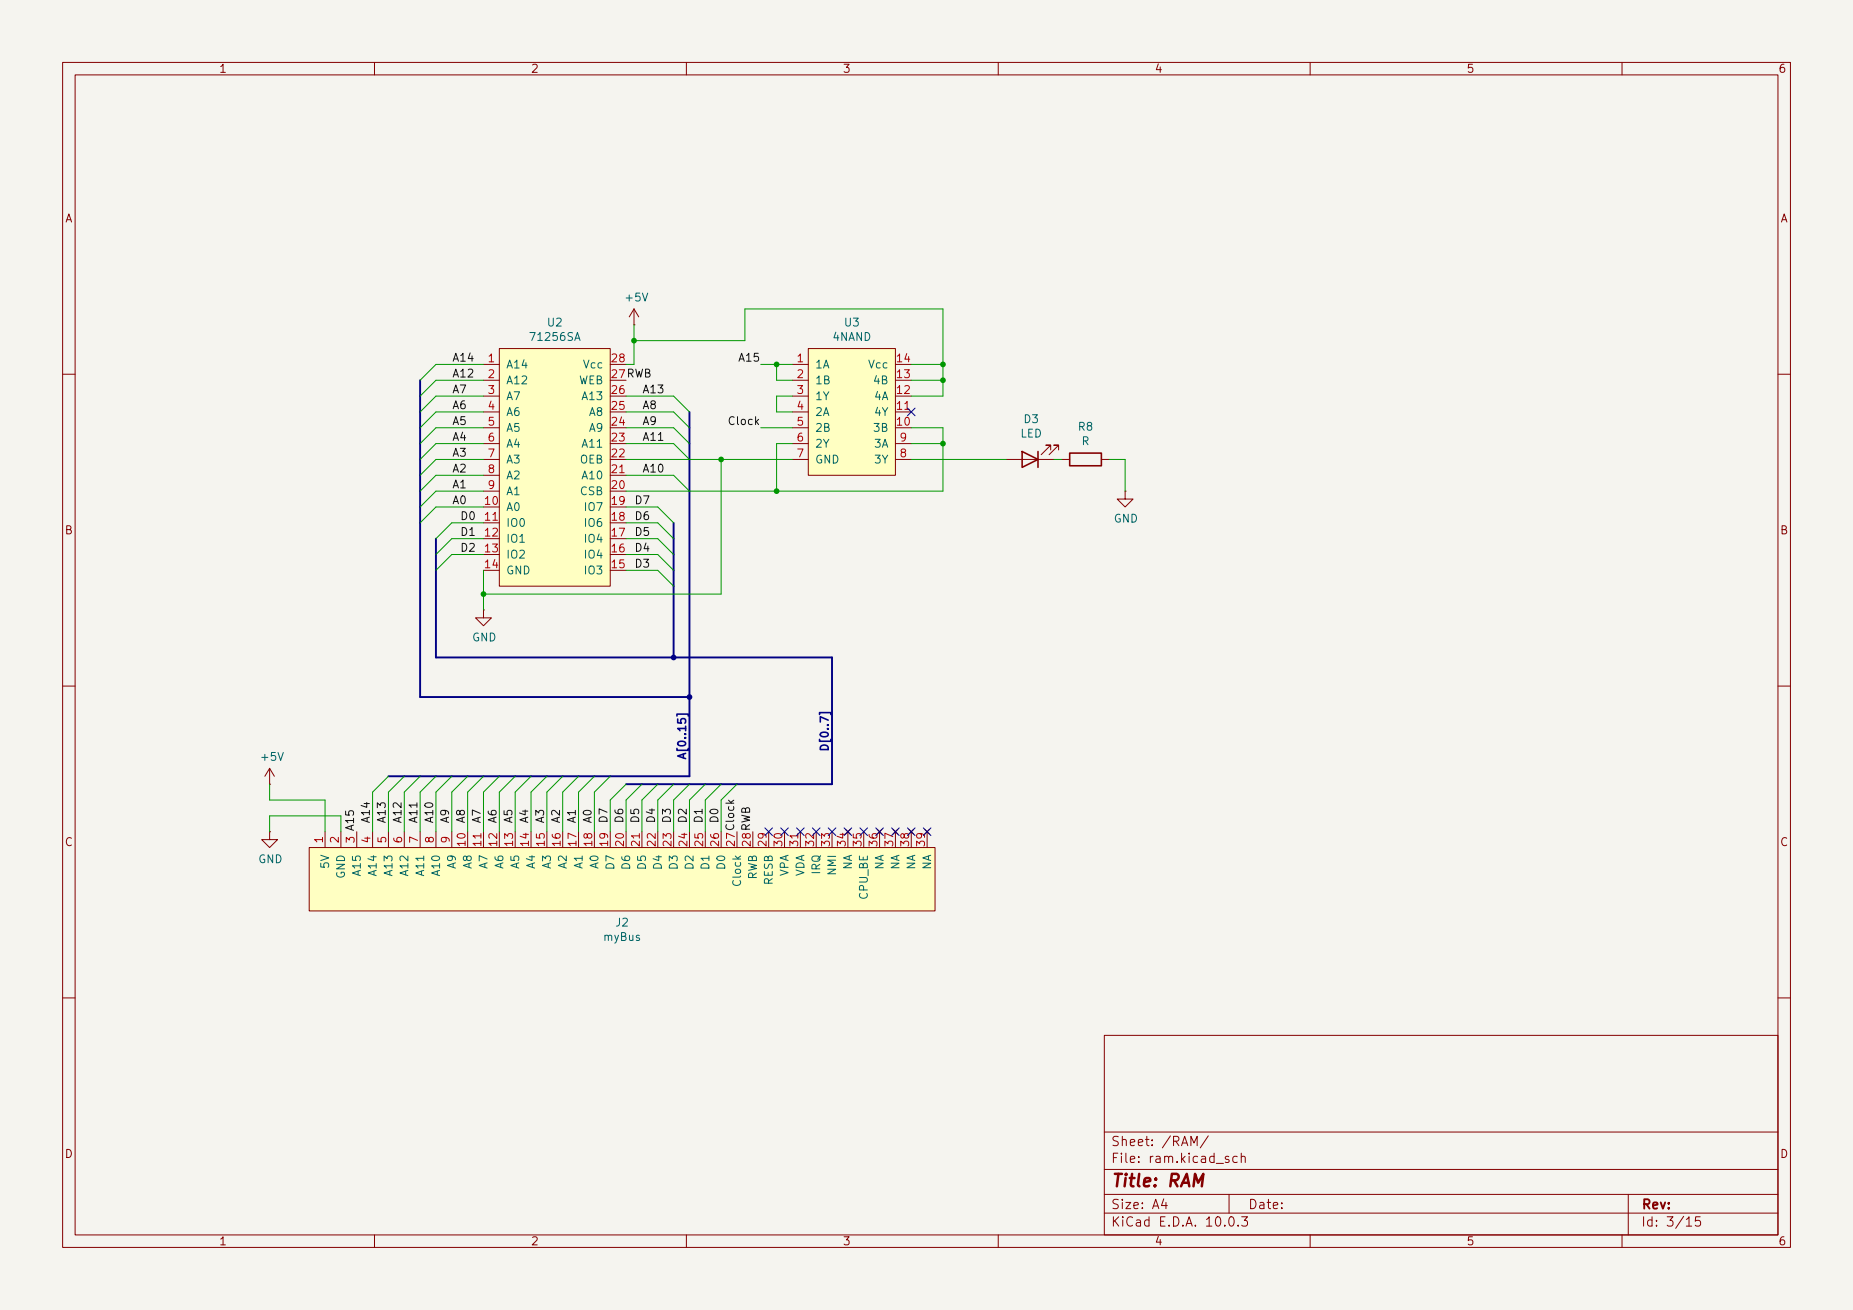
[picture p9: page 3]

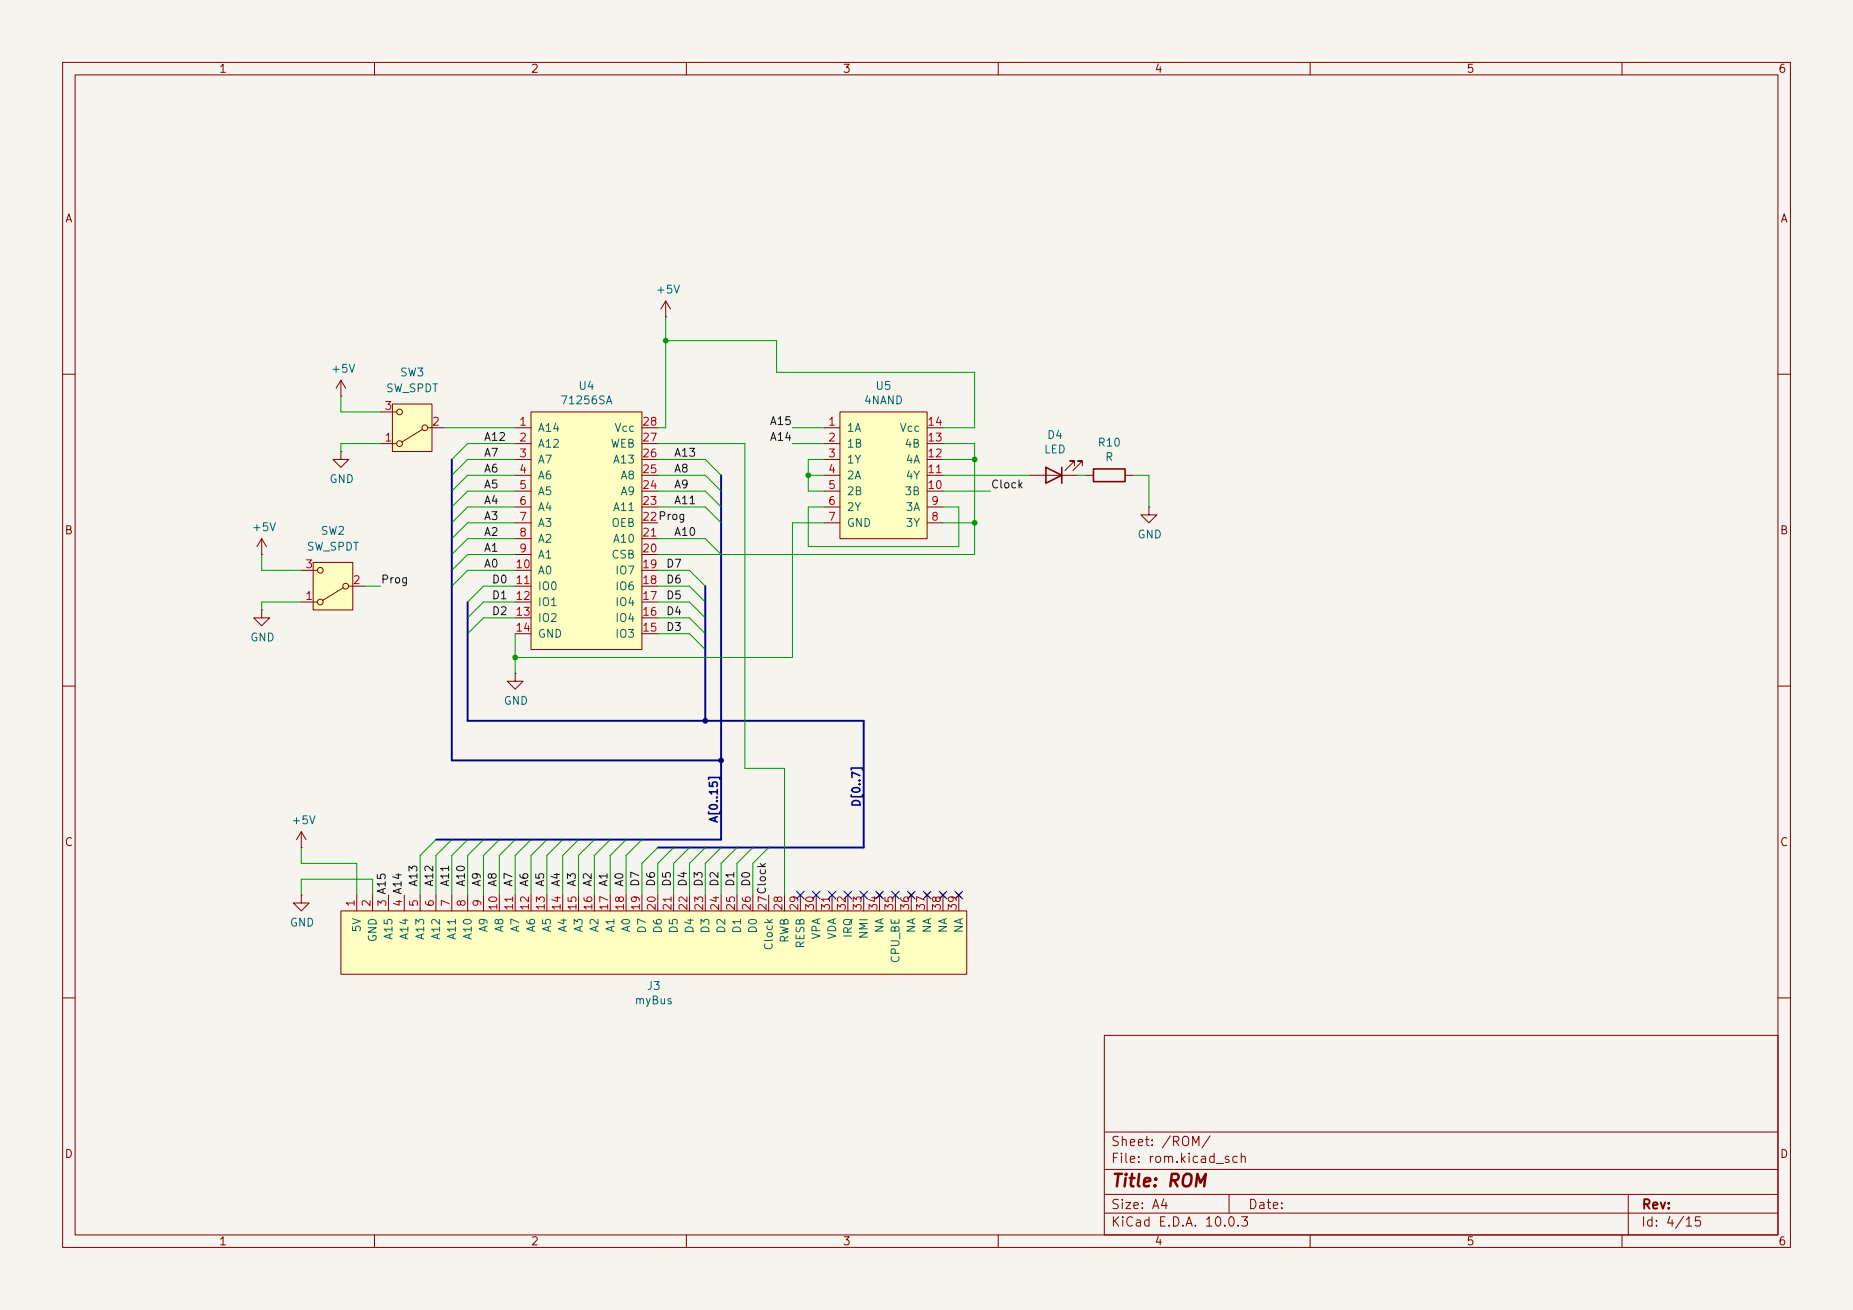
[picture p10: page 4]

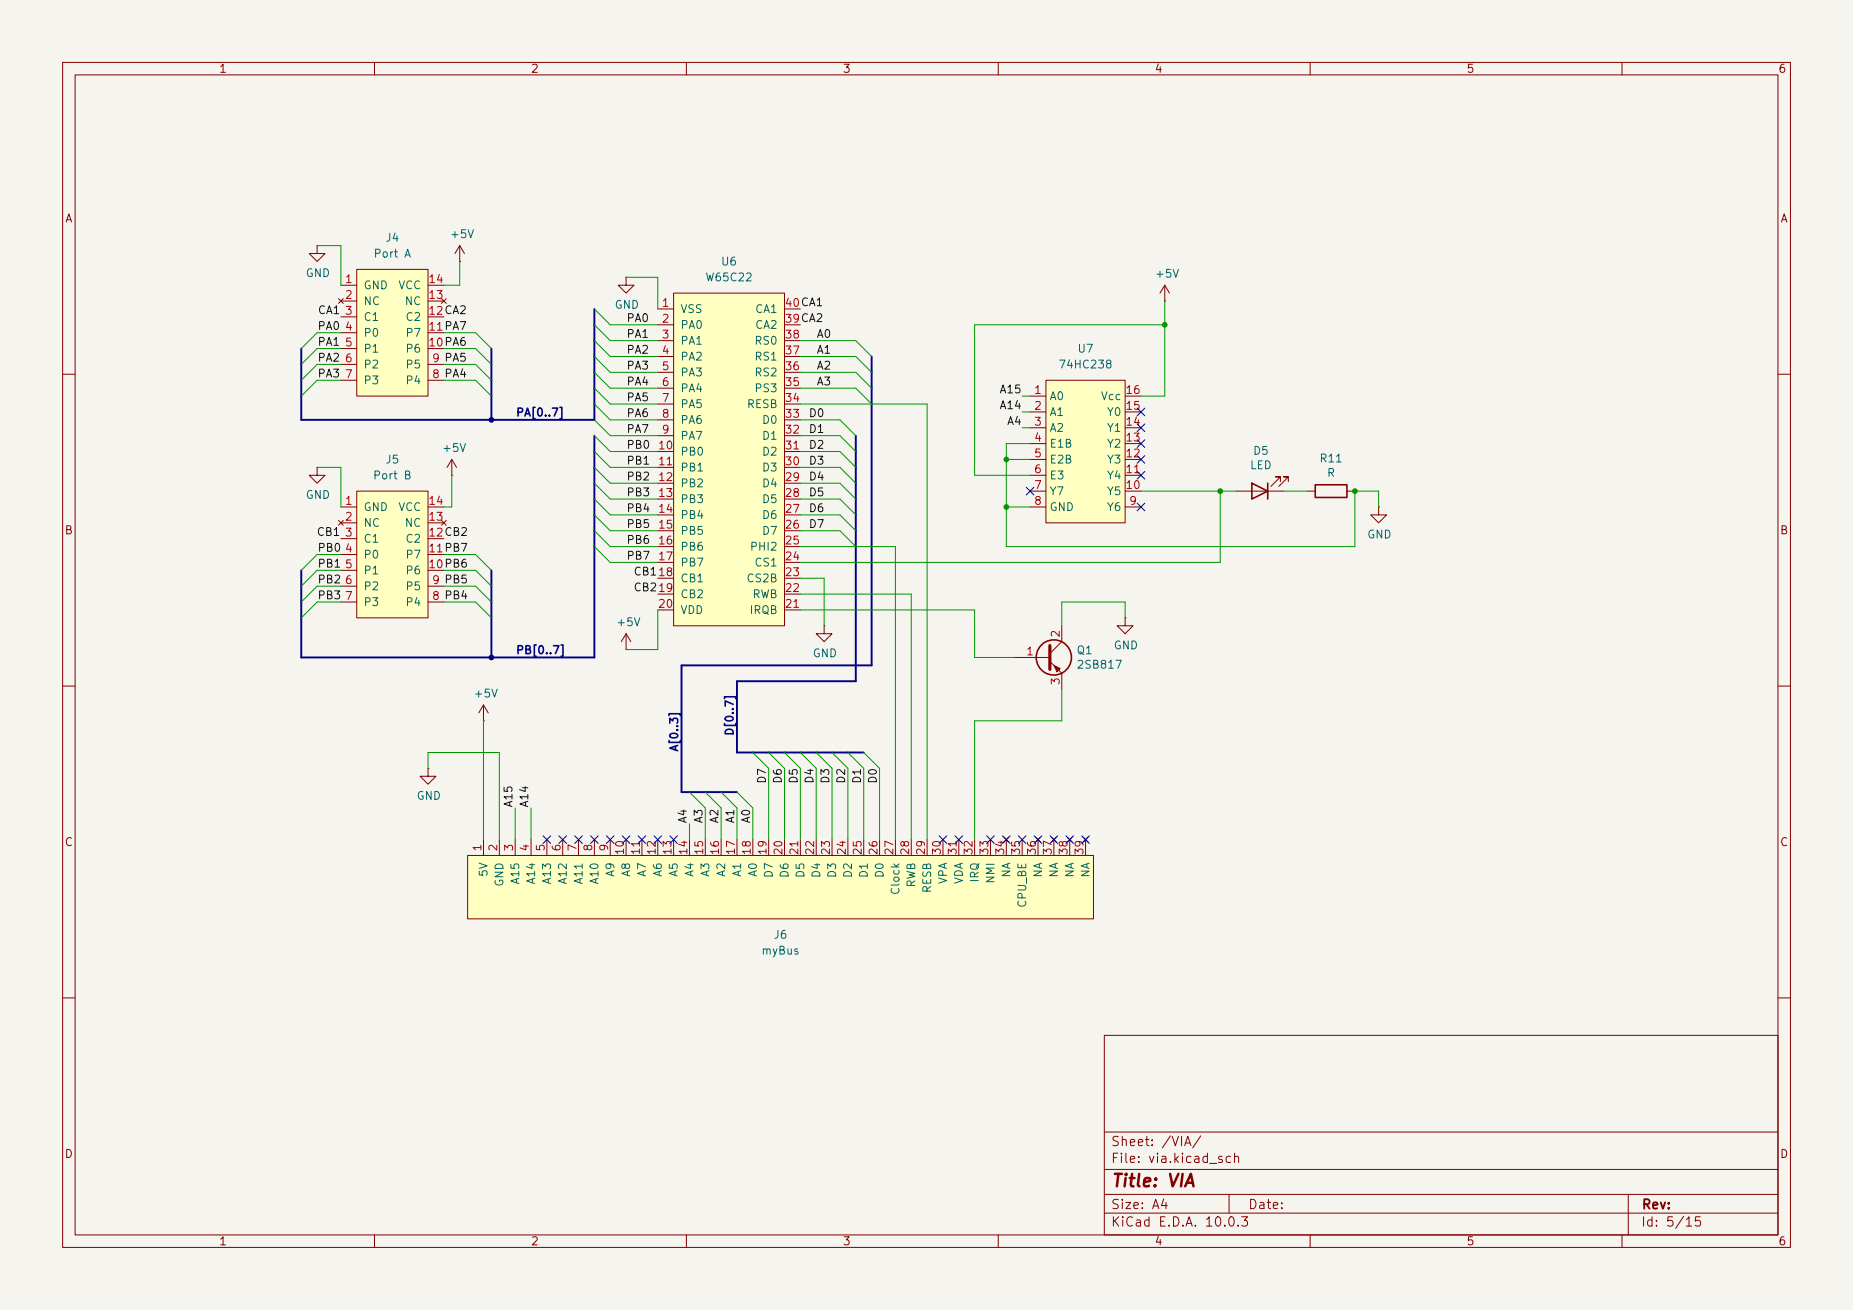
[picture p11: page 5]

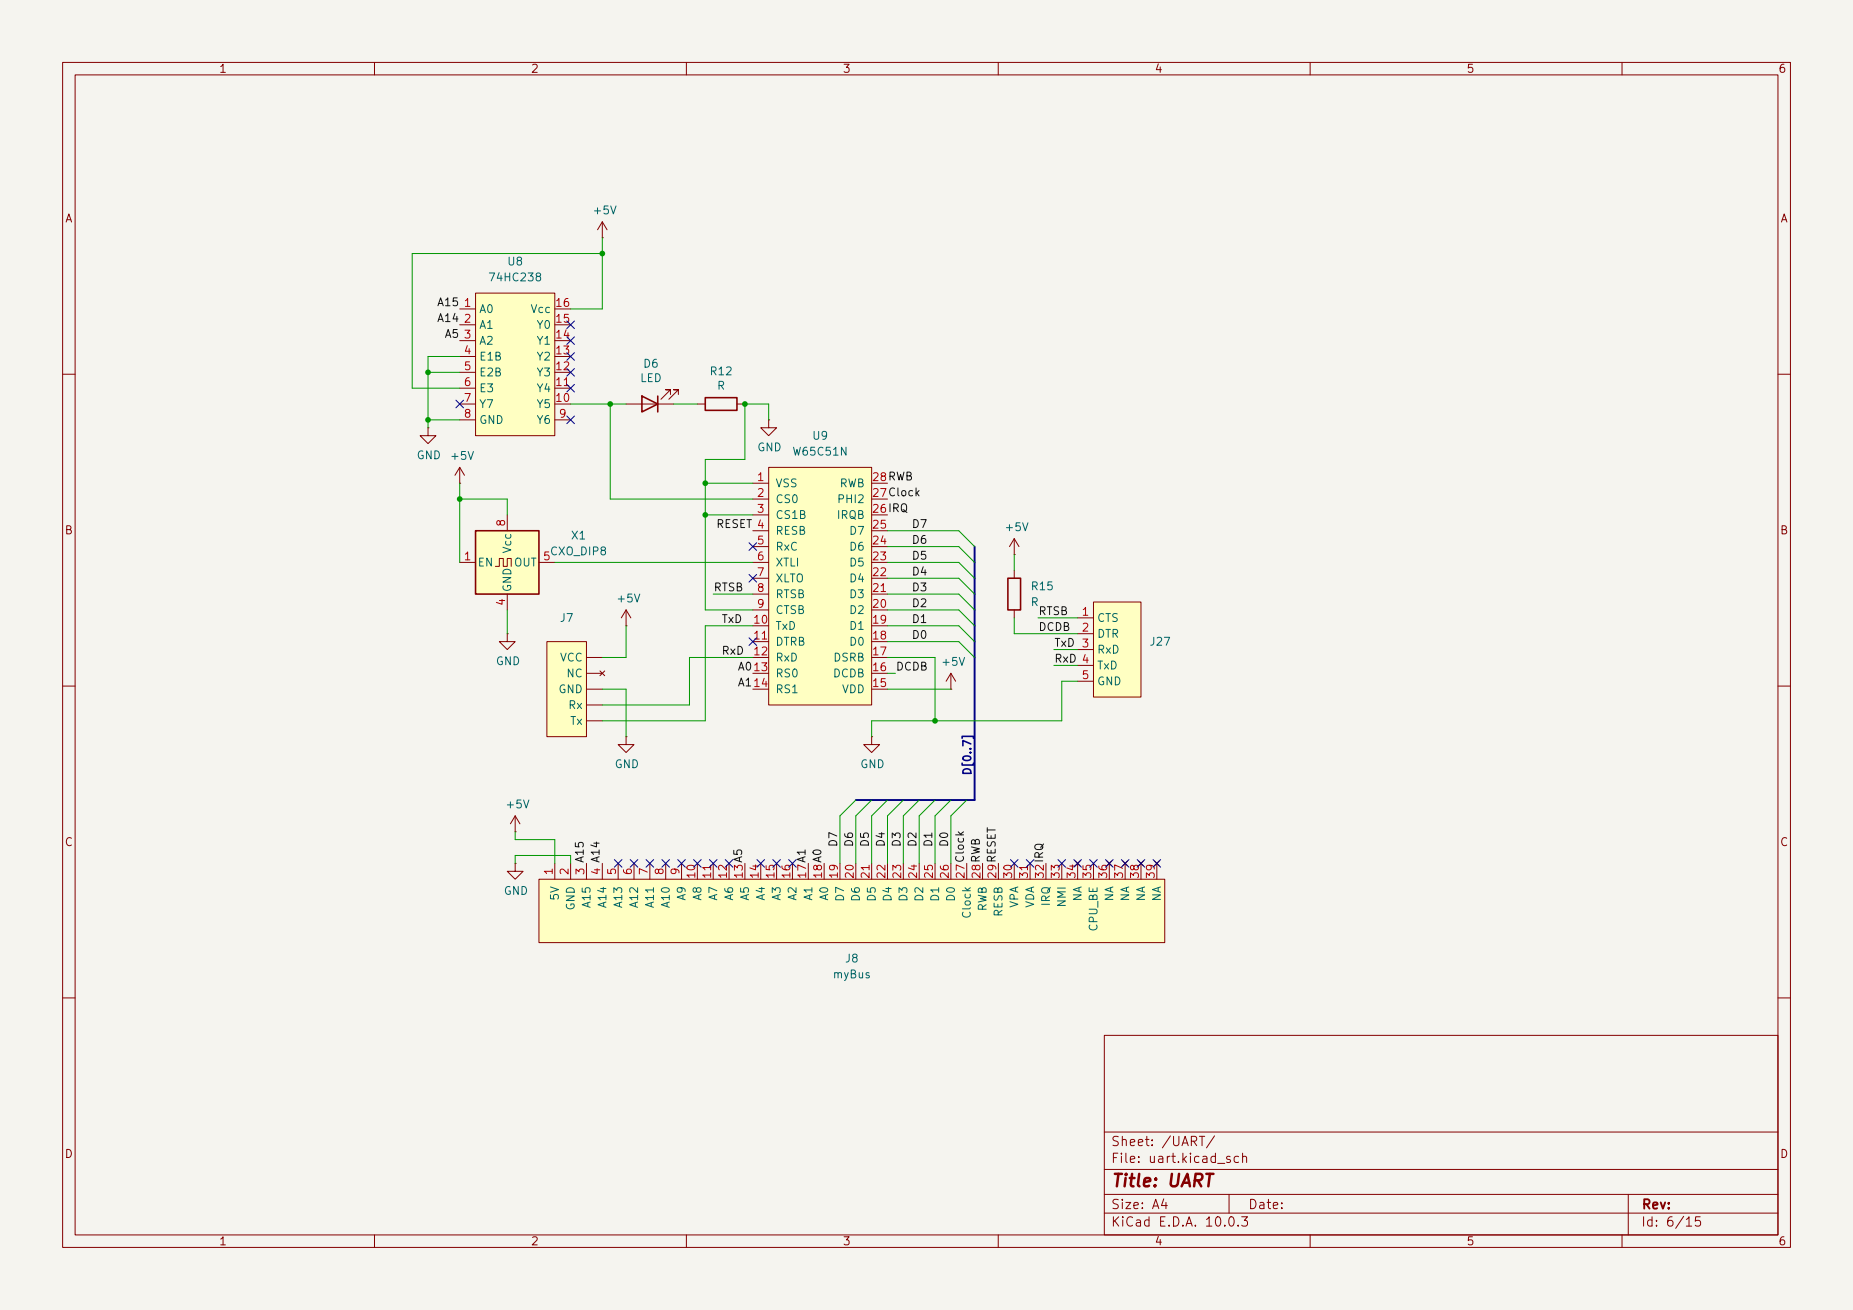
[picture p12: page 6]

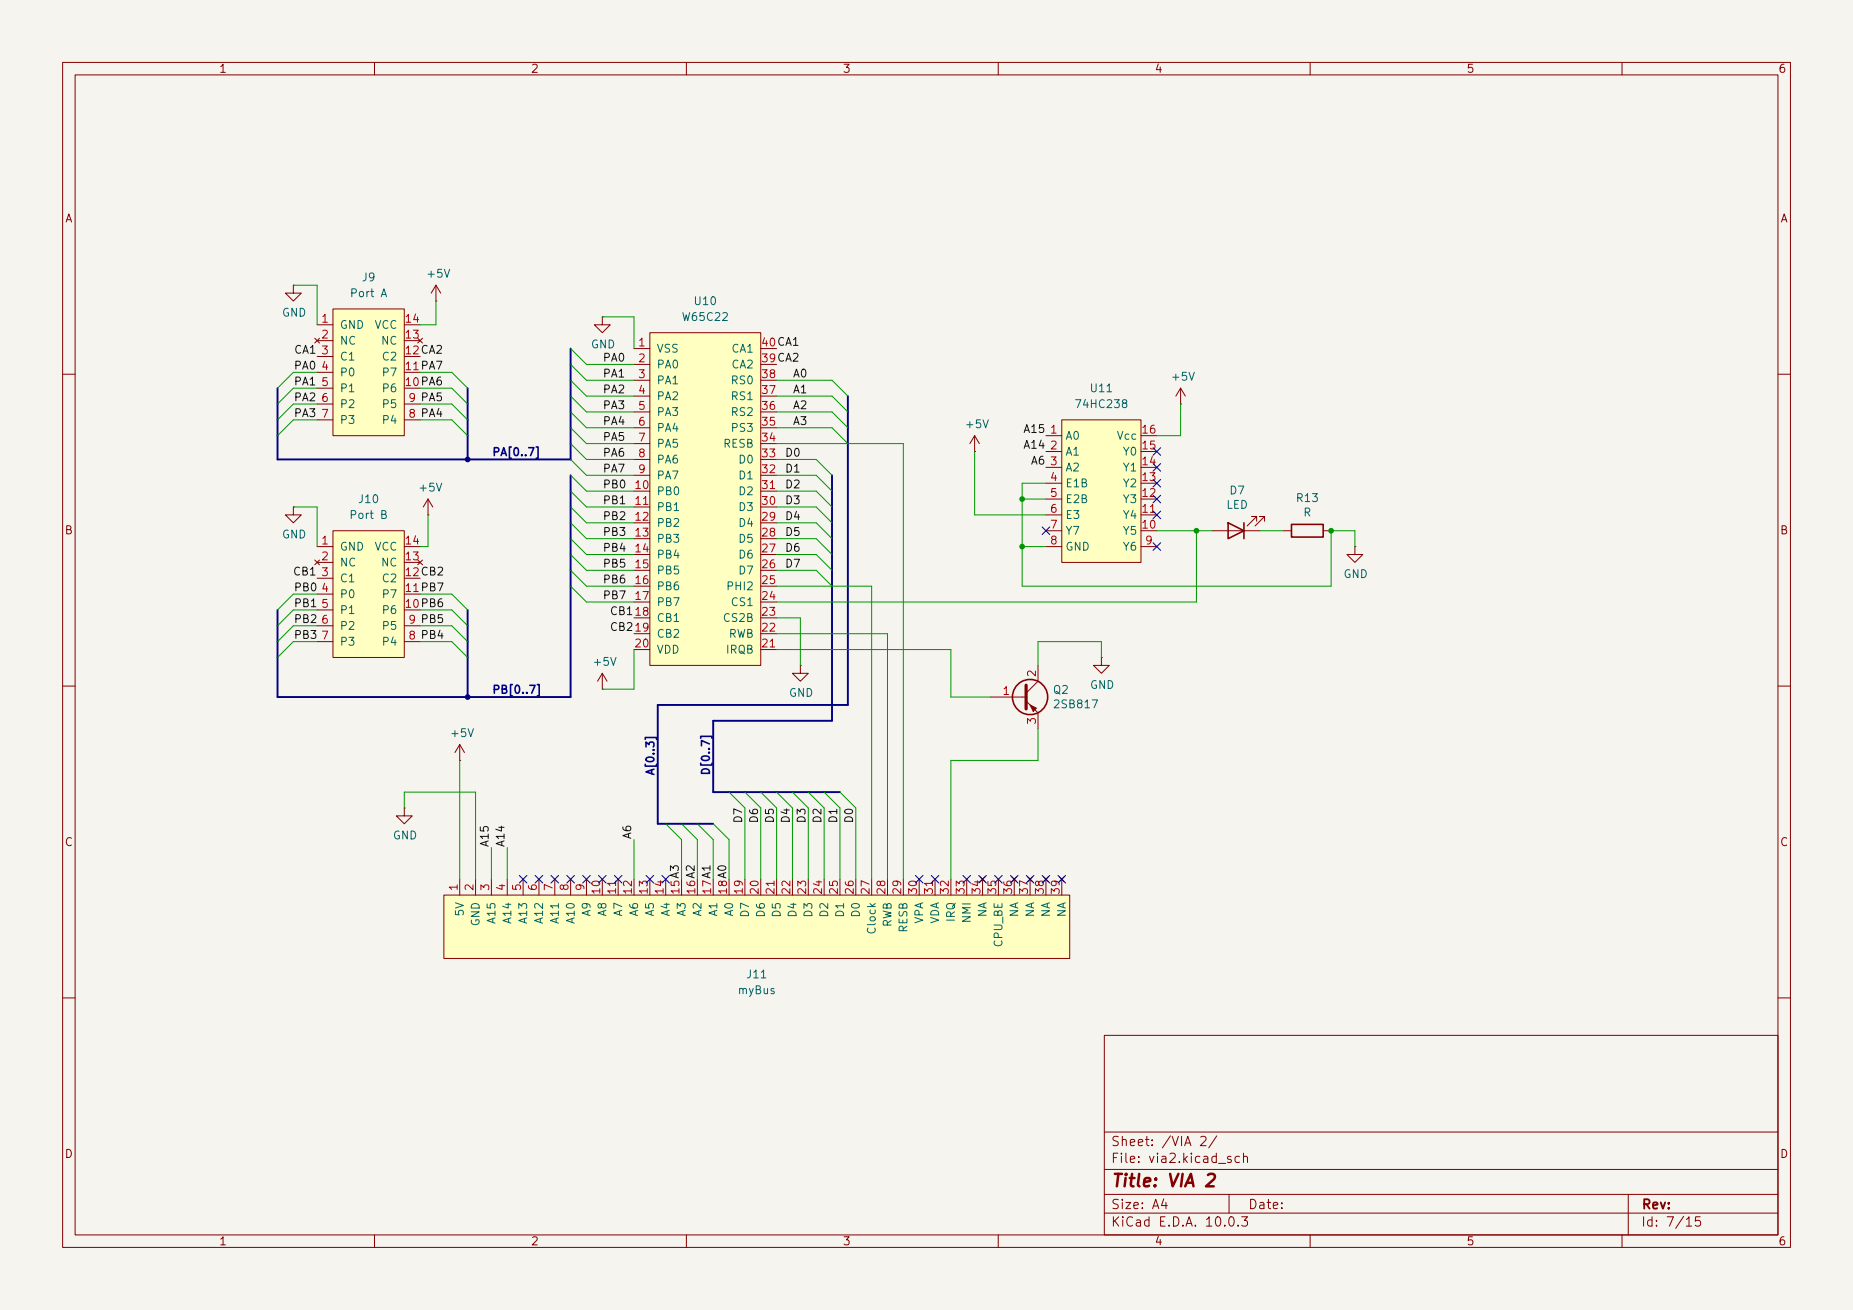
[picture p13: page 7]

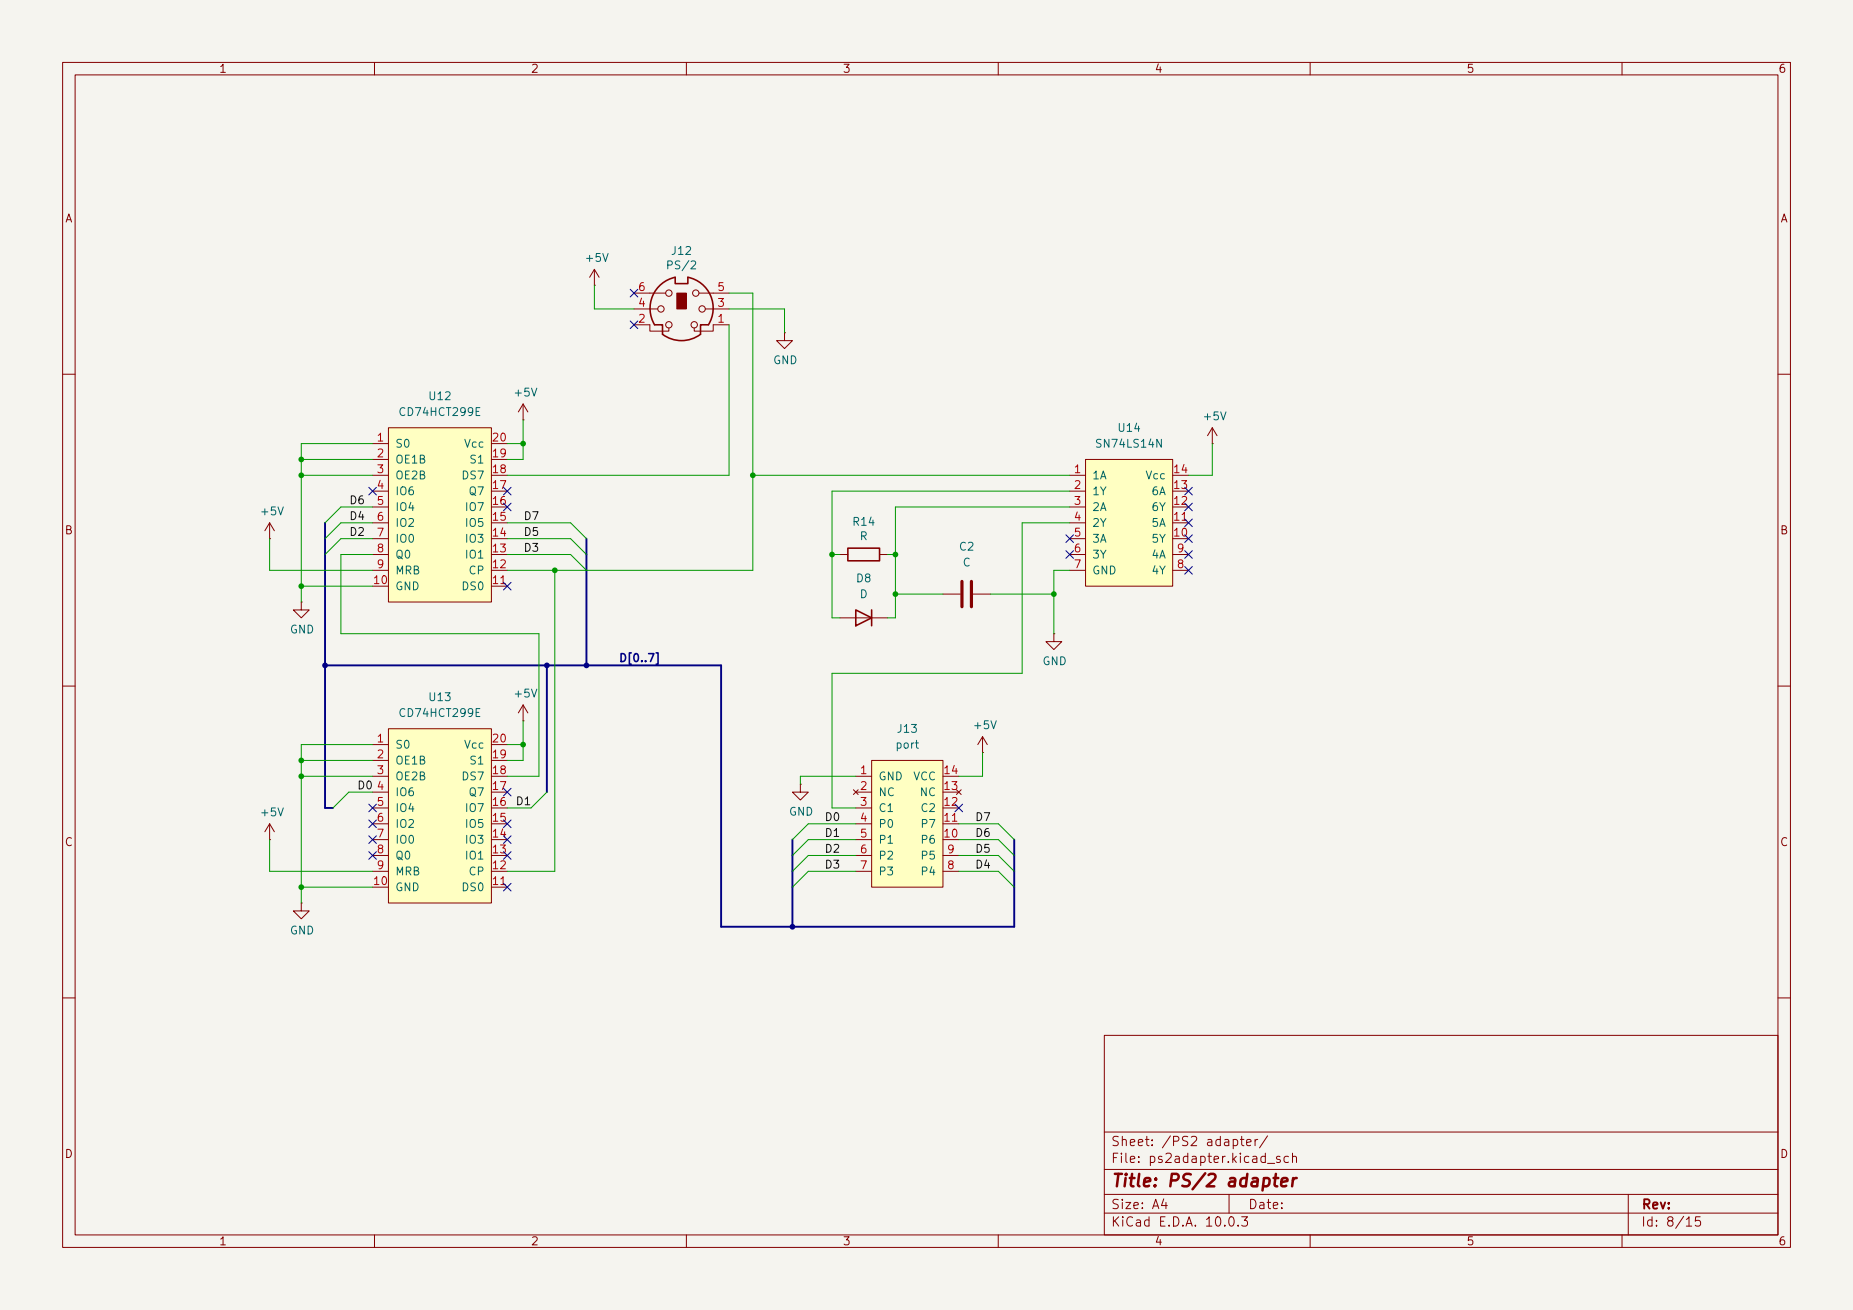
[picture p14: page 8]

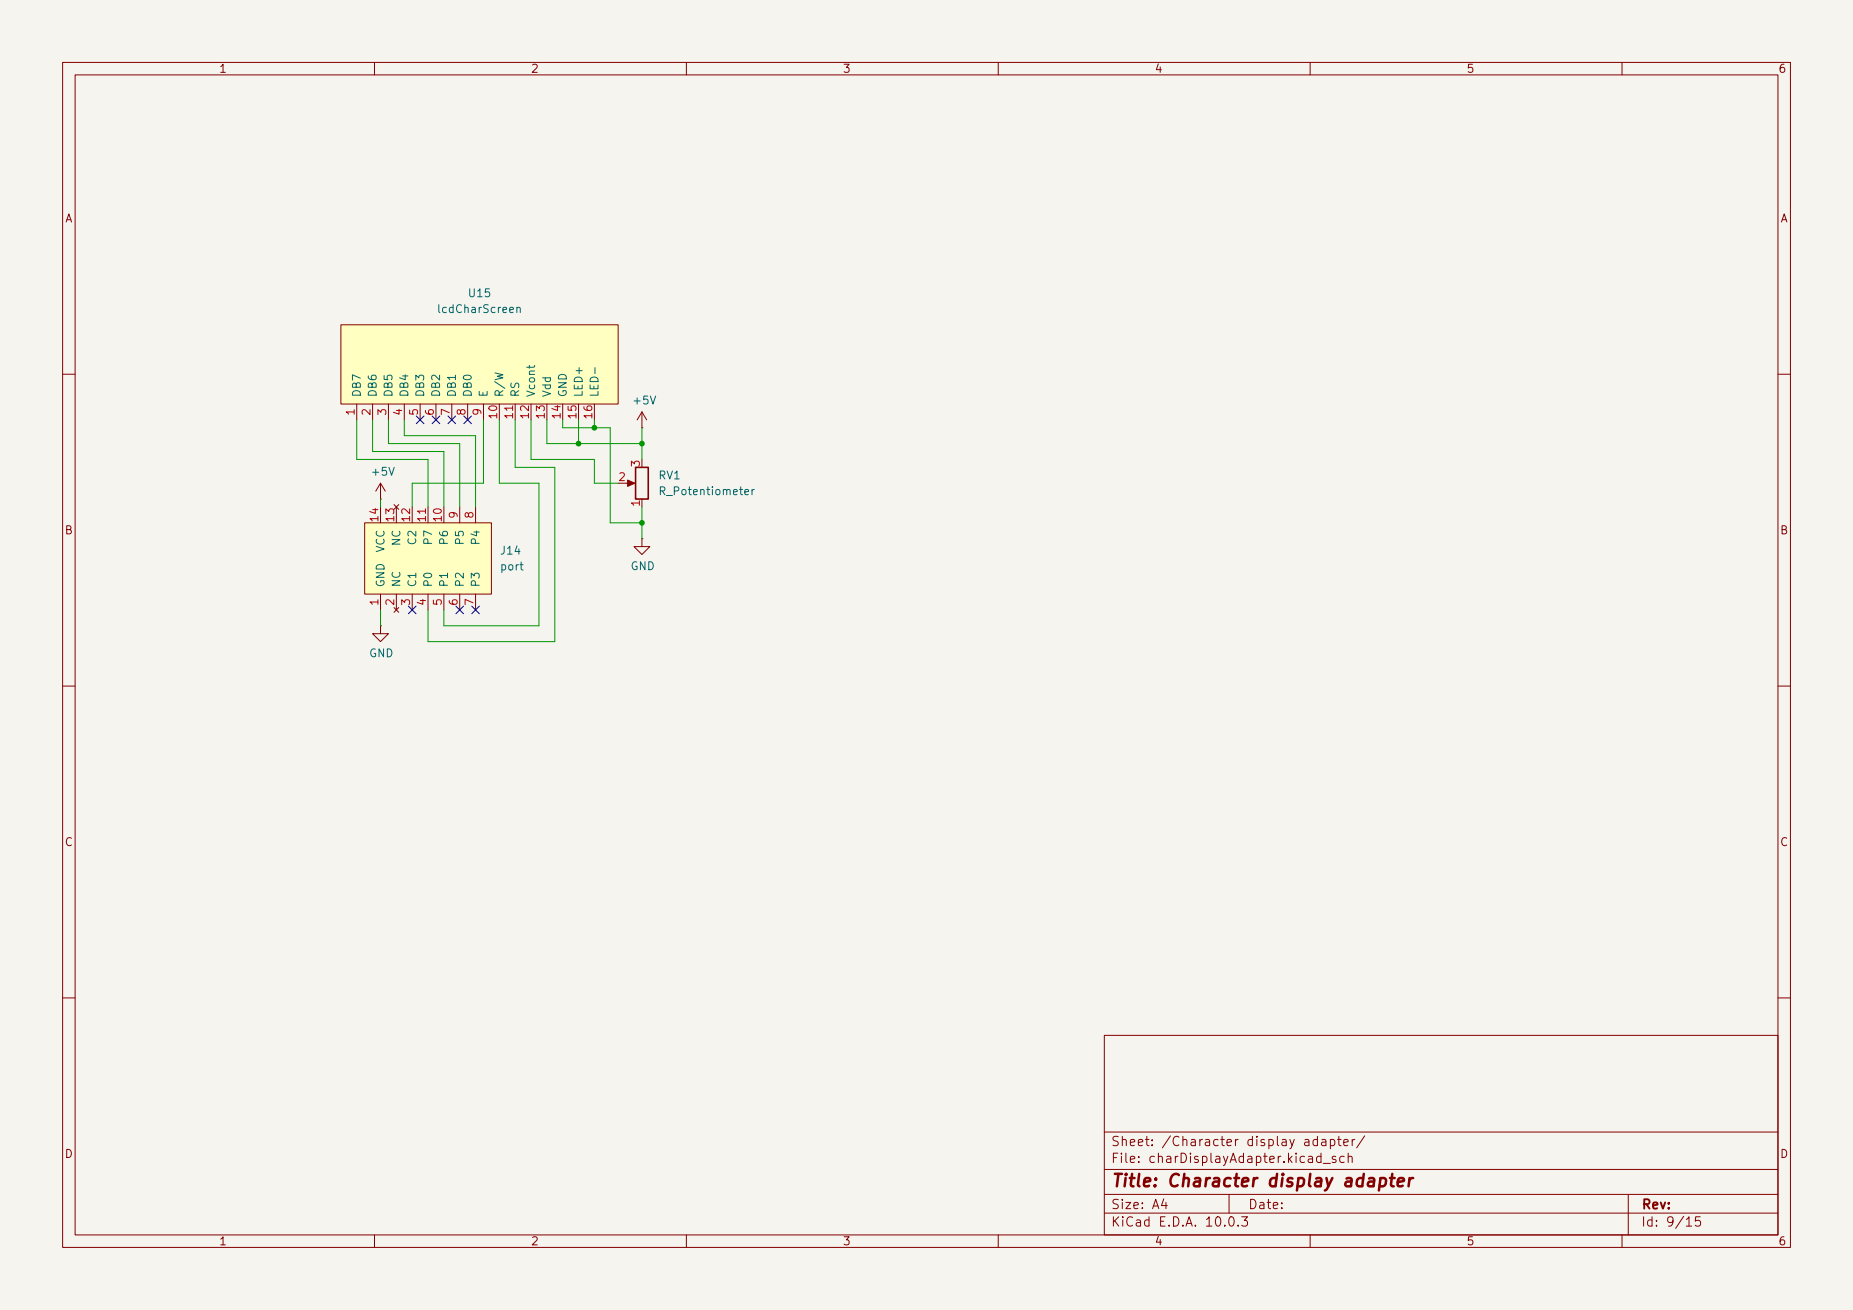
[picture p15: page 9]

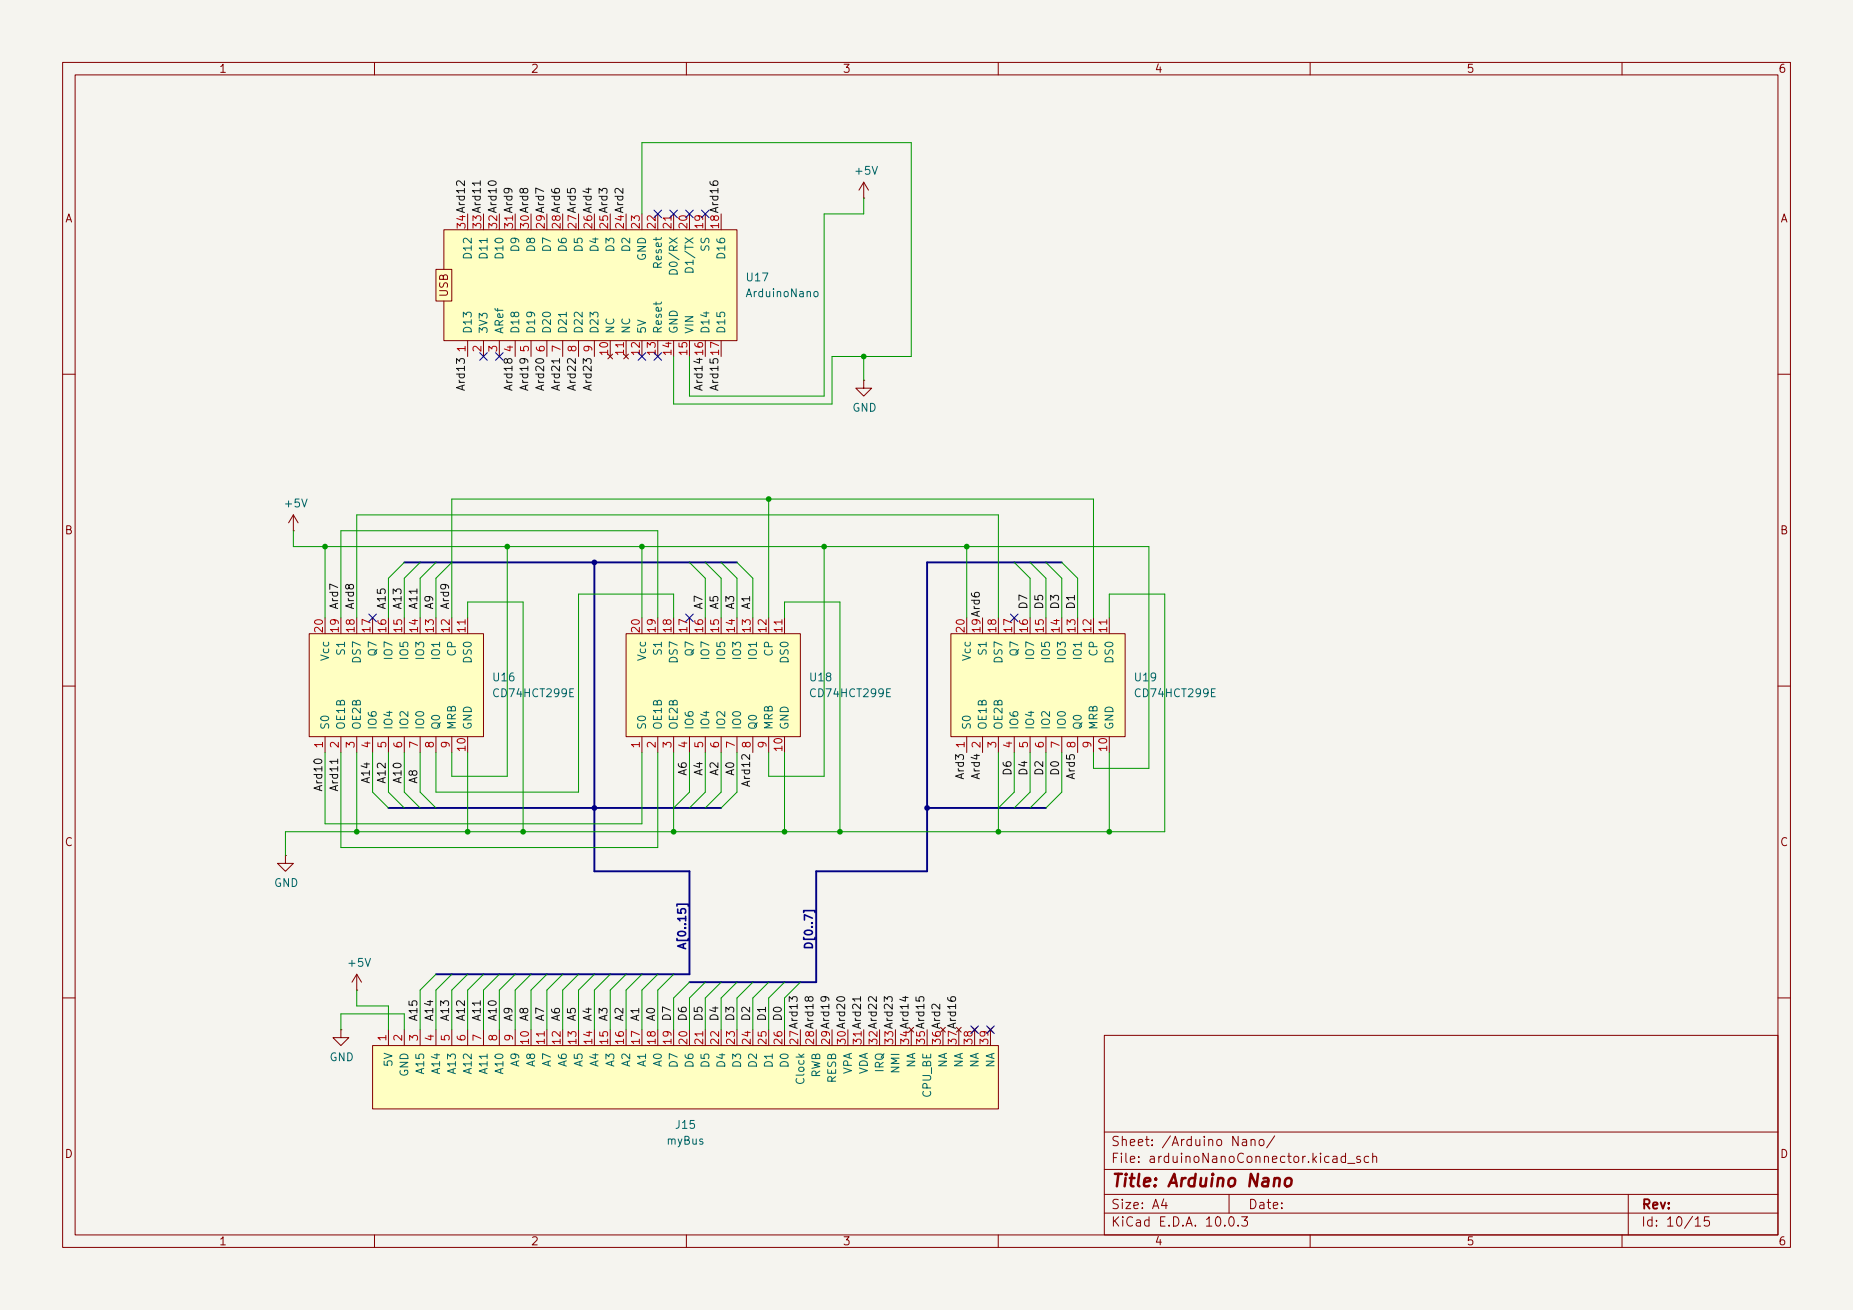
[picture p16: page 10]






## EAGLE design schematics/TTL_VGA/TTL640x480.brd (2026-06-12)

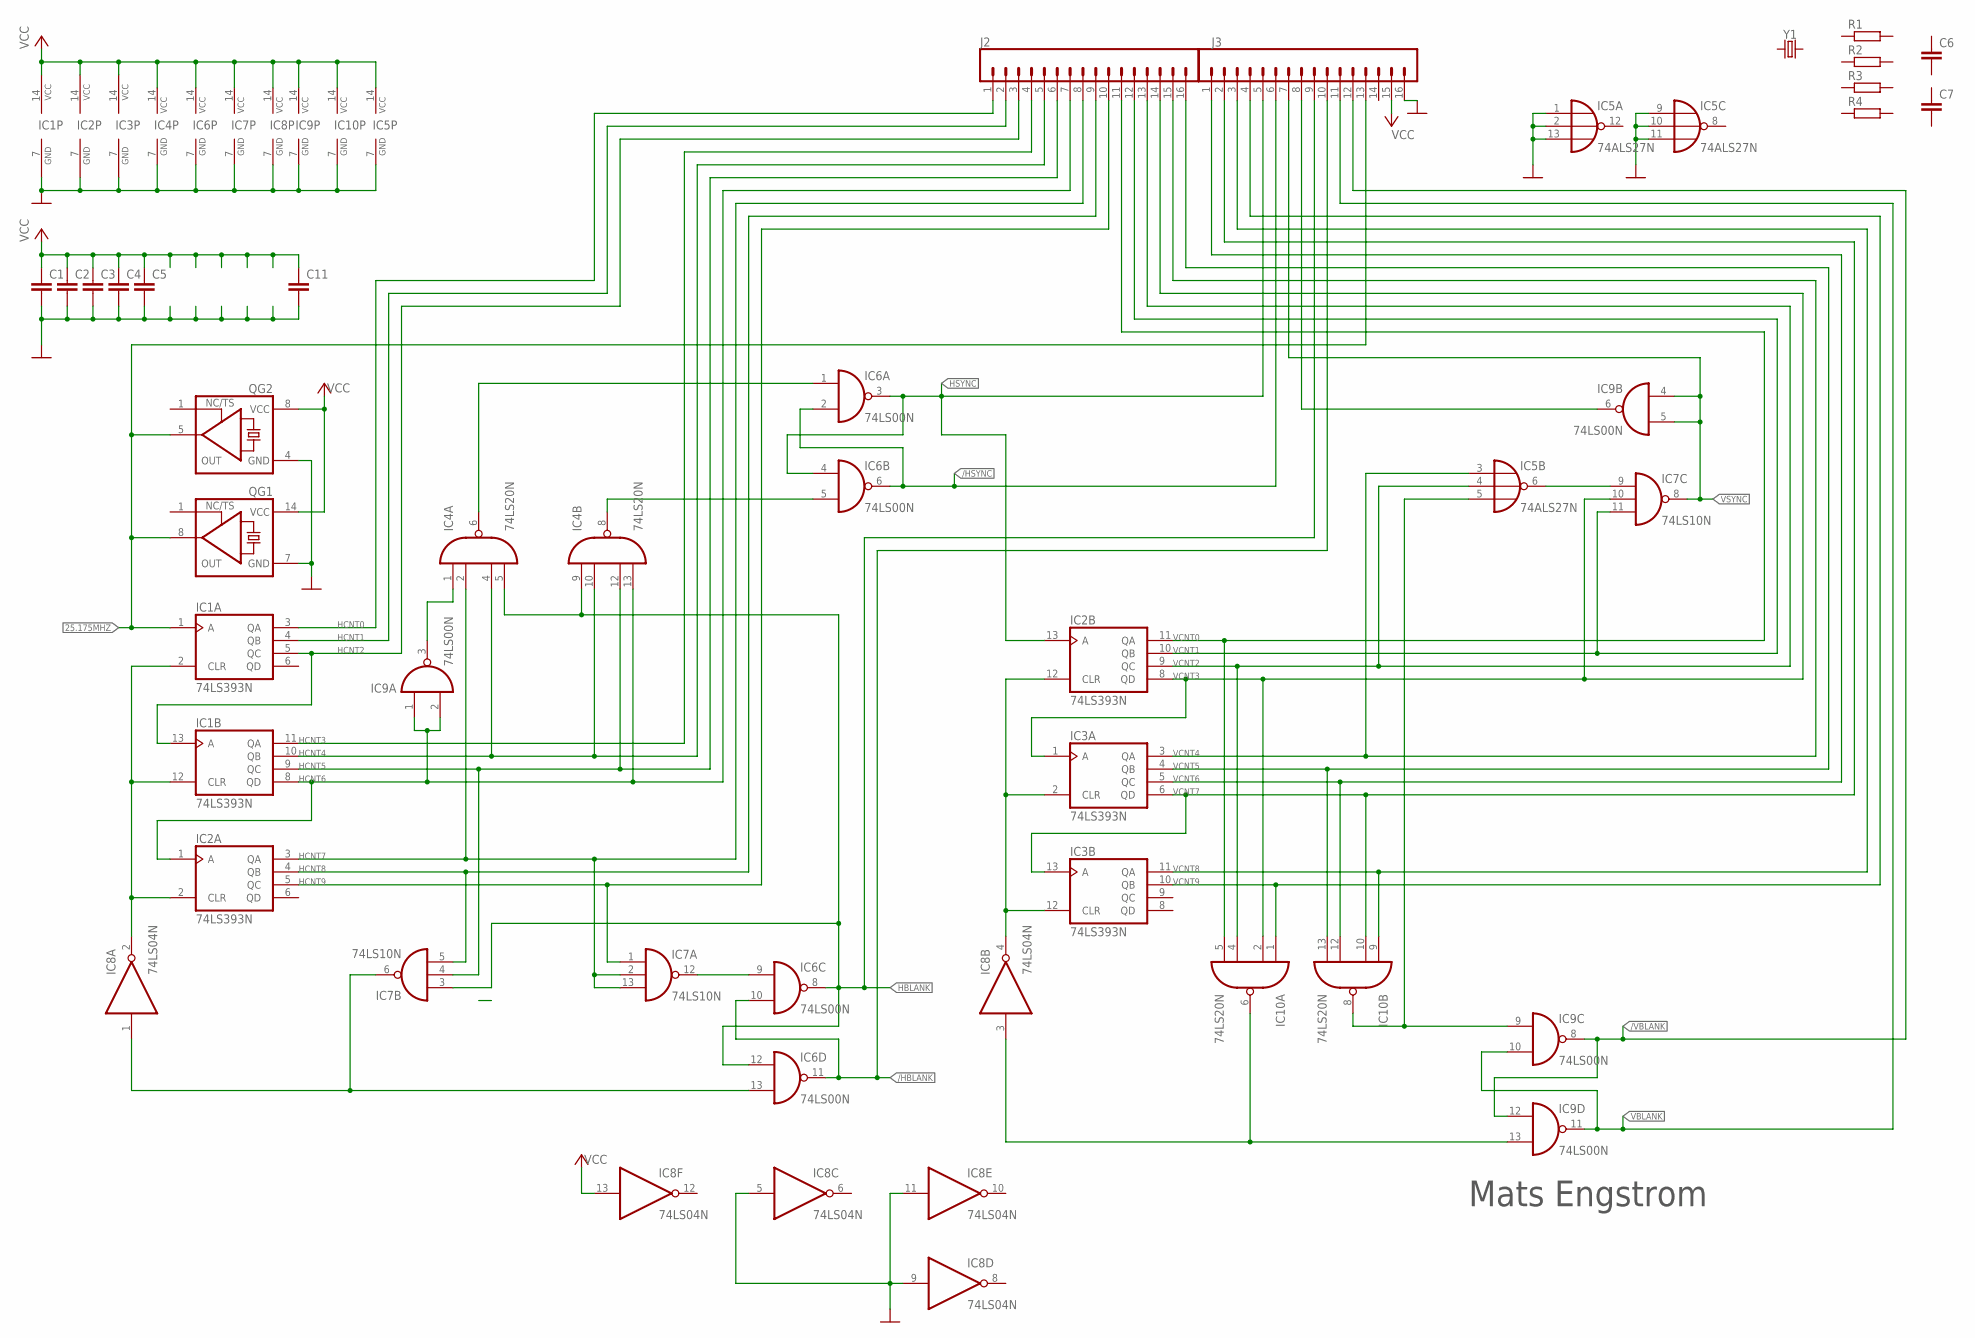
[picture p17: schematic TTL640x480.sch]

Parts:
C1, C2, C3, C4, C5, C6, C7, C11: C-EU050-024X044; C050-024X044
IC1, IC2, IC3: 74LS393N; DIL14
IC4, IC10: 74LS20N; DIL14
IC5: 74ALS27N; DIL14
IC6, IC9: 74LS00N; DIL14
IC7: 74LS10N; DIL14
IC8: 74LS04N; DIL14
J2, J3: CONN_16; 1X16
QG1: XO-14; DIL14S
QG2: XO-8; DIL08S
R1, R2, R3, R4: R-EU_0204/2V; 0204V
Y1: CRYSTALPTH-HC49US; HC49US

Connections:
25.175MHZ: IC1.1 (A), J3.13, QG1.8 (OUT), QG2.5 (OUT)
/HBLANK: IC6.10 (I1), IC6.11 (O), J3.10
/HSYNC: IC6.2 (I1), IC6.6 (O), J3.6
/VBLANK: IC9.8 (O), IC9.12 (I0), J3.12
GND: C1.2, C2.2, C3.2, C4.2, C5.2, C11.2, IC1.7 (GND), IC2.7 (GND), IC3.7 (GND), IC4.7 (GND), IC5.1 (I0), IC5.2 (I1), IC5.7 (GND), IC5.9 (I0), IC5.10 (I1), IC5.11 (I2), IC5.13 (I2), IC6.7 (GND), IC7.7 (GND), IC8.5 (I), IC8.7 (GND), IC8.9 (I), IC8.11 (I), IC9.7 (GND), IC10.7 (GND), J3.16, QG1.7 (GND), QG2.4 (GND)
HBLANK: IC4.5 (I3), IC4.9 (I0), IC6.8 (O), IC6.12 (I0), IC7.3 (I0), J3.9
HCNT0: IC1.3 (QA), J2.1
HCNT1: IC1.4 (QB), J2.2
HCNT2: IC1.5 (QC), IC1.13 (A), J2.3
HCNT3: IC1.11 (QA), J2.4
HCNT4: IC1.10 (QB), IC4.4 (I2), IC4.10 (I1), J2.5
HCNT5: IC1.9 (QC), IC4.12 (I2), IC7.4 (I1), J2.6
HCNT6: IC1.8 (QD), IC2.1 (A), IC4.13 (I3), IC9.1 (I0), IC9.2 (I1), J2.7
HCNT7: IC2.3 (QA), IC4.2 (I1), IC7.2 (I1), IC7.13 (I2), J2.8
HCNT8: IC2.4 (QB), IC7.5 (I2), J2.9
HCNT9: IC2.5 (QC), IC7.1 (I0), J2.10
HSYNC: IC2.13 (A), IC6.3 (O), IC6.4 (I0), J3.5
unnamed: IC9.6 (O), J3.8
unnamed: IC4.1 (I0), IC9.3 (O)
unnamed: IC1.2 (CLR), IC1.12 (CLR), IC2.2 (CLR), IC8.2 (O)
unnamed: IC5.5 (I2), IC9.9 (I0), IC10.8 (O)
unnamed: IC5.6 (O), IC7.9 (I0)
unnamed: IC2.12 (CLR), IC3.2 (CLR), IC3.12 (CLR), IC8.4 (O)
unnamed: IC8.3 (I), IC9.13 (I1), IC10.6 (O)
unnamed: IC4.6 (O), IC6.1 (I0)
unnamed: IC4.8 (O), IC6.5 (I1)
unnamed: IC6.9 (I0), IC7.12 (O)
unnamed: IC6.13 (I1), IC7.6 (O), IC8.1 (I)
VBLANK: IC9.10 (I1), IC9.11 (O), J3.11
VCC: C1.1, C2.1, C3.1, C4.1, C5.1, C11.1, IC1.14 (VCC), IC2.14 (VCC), IC3.14 (VCC), IC4.14 (VCC), IC5.14 (VCC), IC6.14 (VCC), IC7.14 (VCC), IC8.13 (I), IC8.14 (VCC), IC9.14 (VCC), IC10.14 (VCC), J3.15, QG1.14 (VCC), QG2.8 (VCC)
VCNT0: IC2.11 (QA), IC10.5 (I3), J2.11
VCNT1: IC2.10 (QB), IC7.11 (I2), J2.12
VCNT2: IC2.9 (QC), IC5.4 (I1), IC10.4 (I2), J2.13
VCNT3: IC2.8 (QD), IC3.1 (A), IC7.10 (I1), IC10.2 (I1), J2.14
VCNT4: IC3.3 (QA), IC5.3 (I0), J2.15
VCNT5: IC3.4 (QB), IC10.13 (I3), J2.16
VCNT6: IC3.5 (QC), IC10.12 (I2), J3.1
VCNT7: IC3.6 (QD), IC3.13 (A), IC10.10 (I1), J3.2
VCNT8: IC3.11 (QA), IC10.9 (I0), J3.3
VCNT9: IC3.10 (QB), IC10.1 (I0), J3.4
VSYNC: IC7.8 (O), IC9.4 (I0), IC9.5 (I1), J3.7

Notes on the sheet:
Mats Engstrom

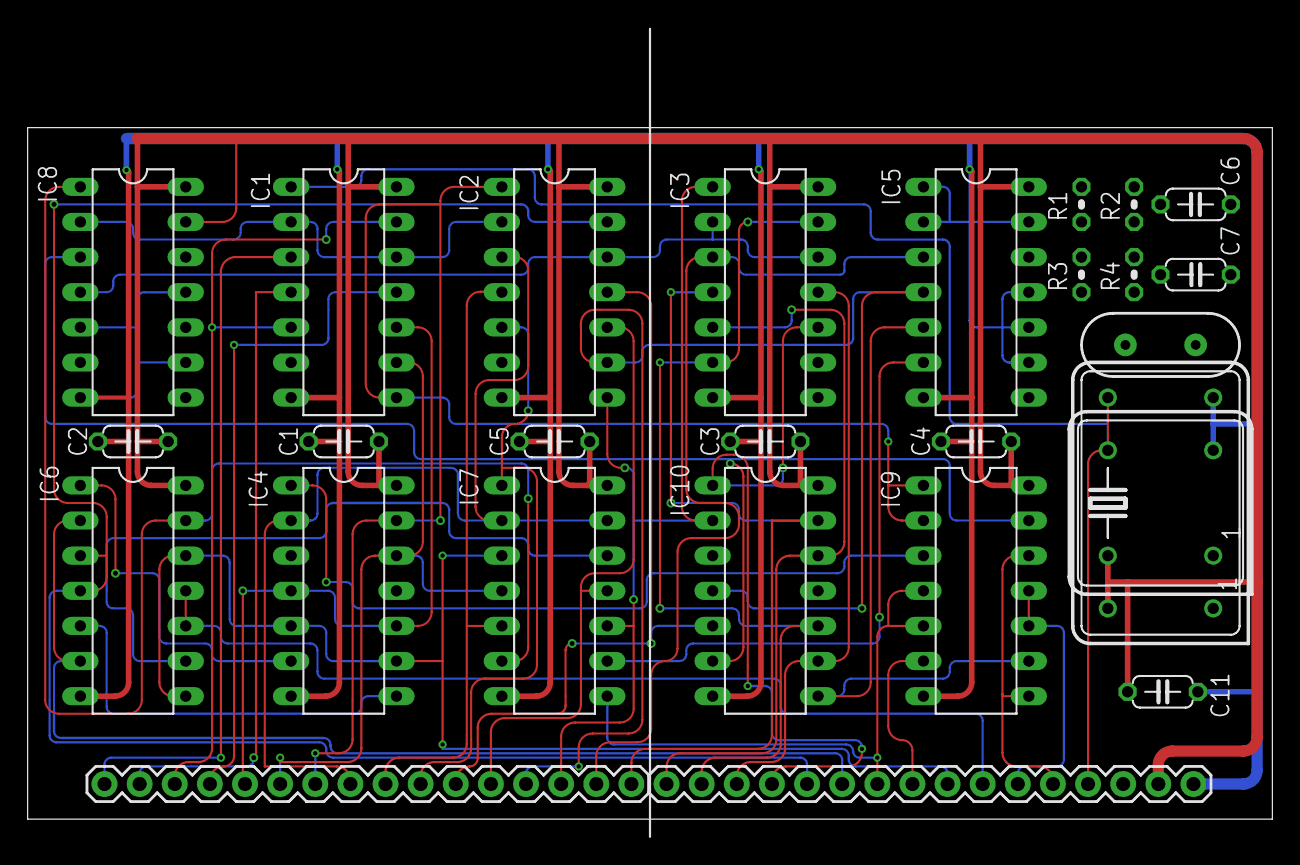
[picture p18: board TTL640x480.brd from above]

Board: 2 copper layers, 90.0 x 50.0 mm, 27 parts (0 on the bottom side), 41 nets.

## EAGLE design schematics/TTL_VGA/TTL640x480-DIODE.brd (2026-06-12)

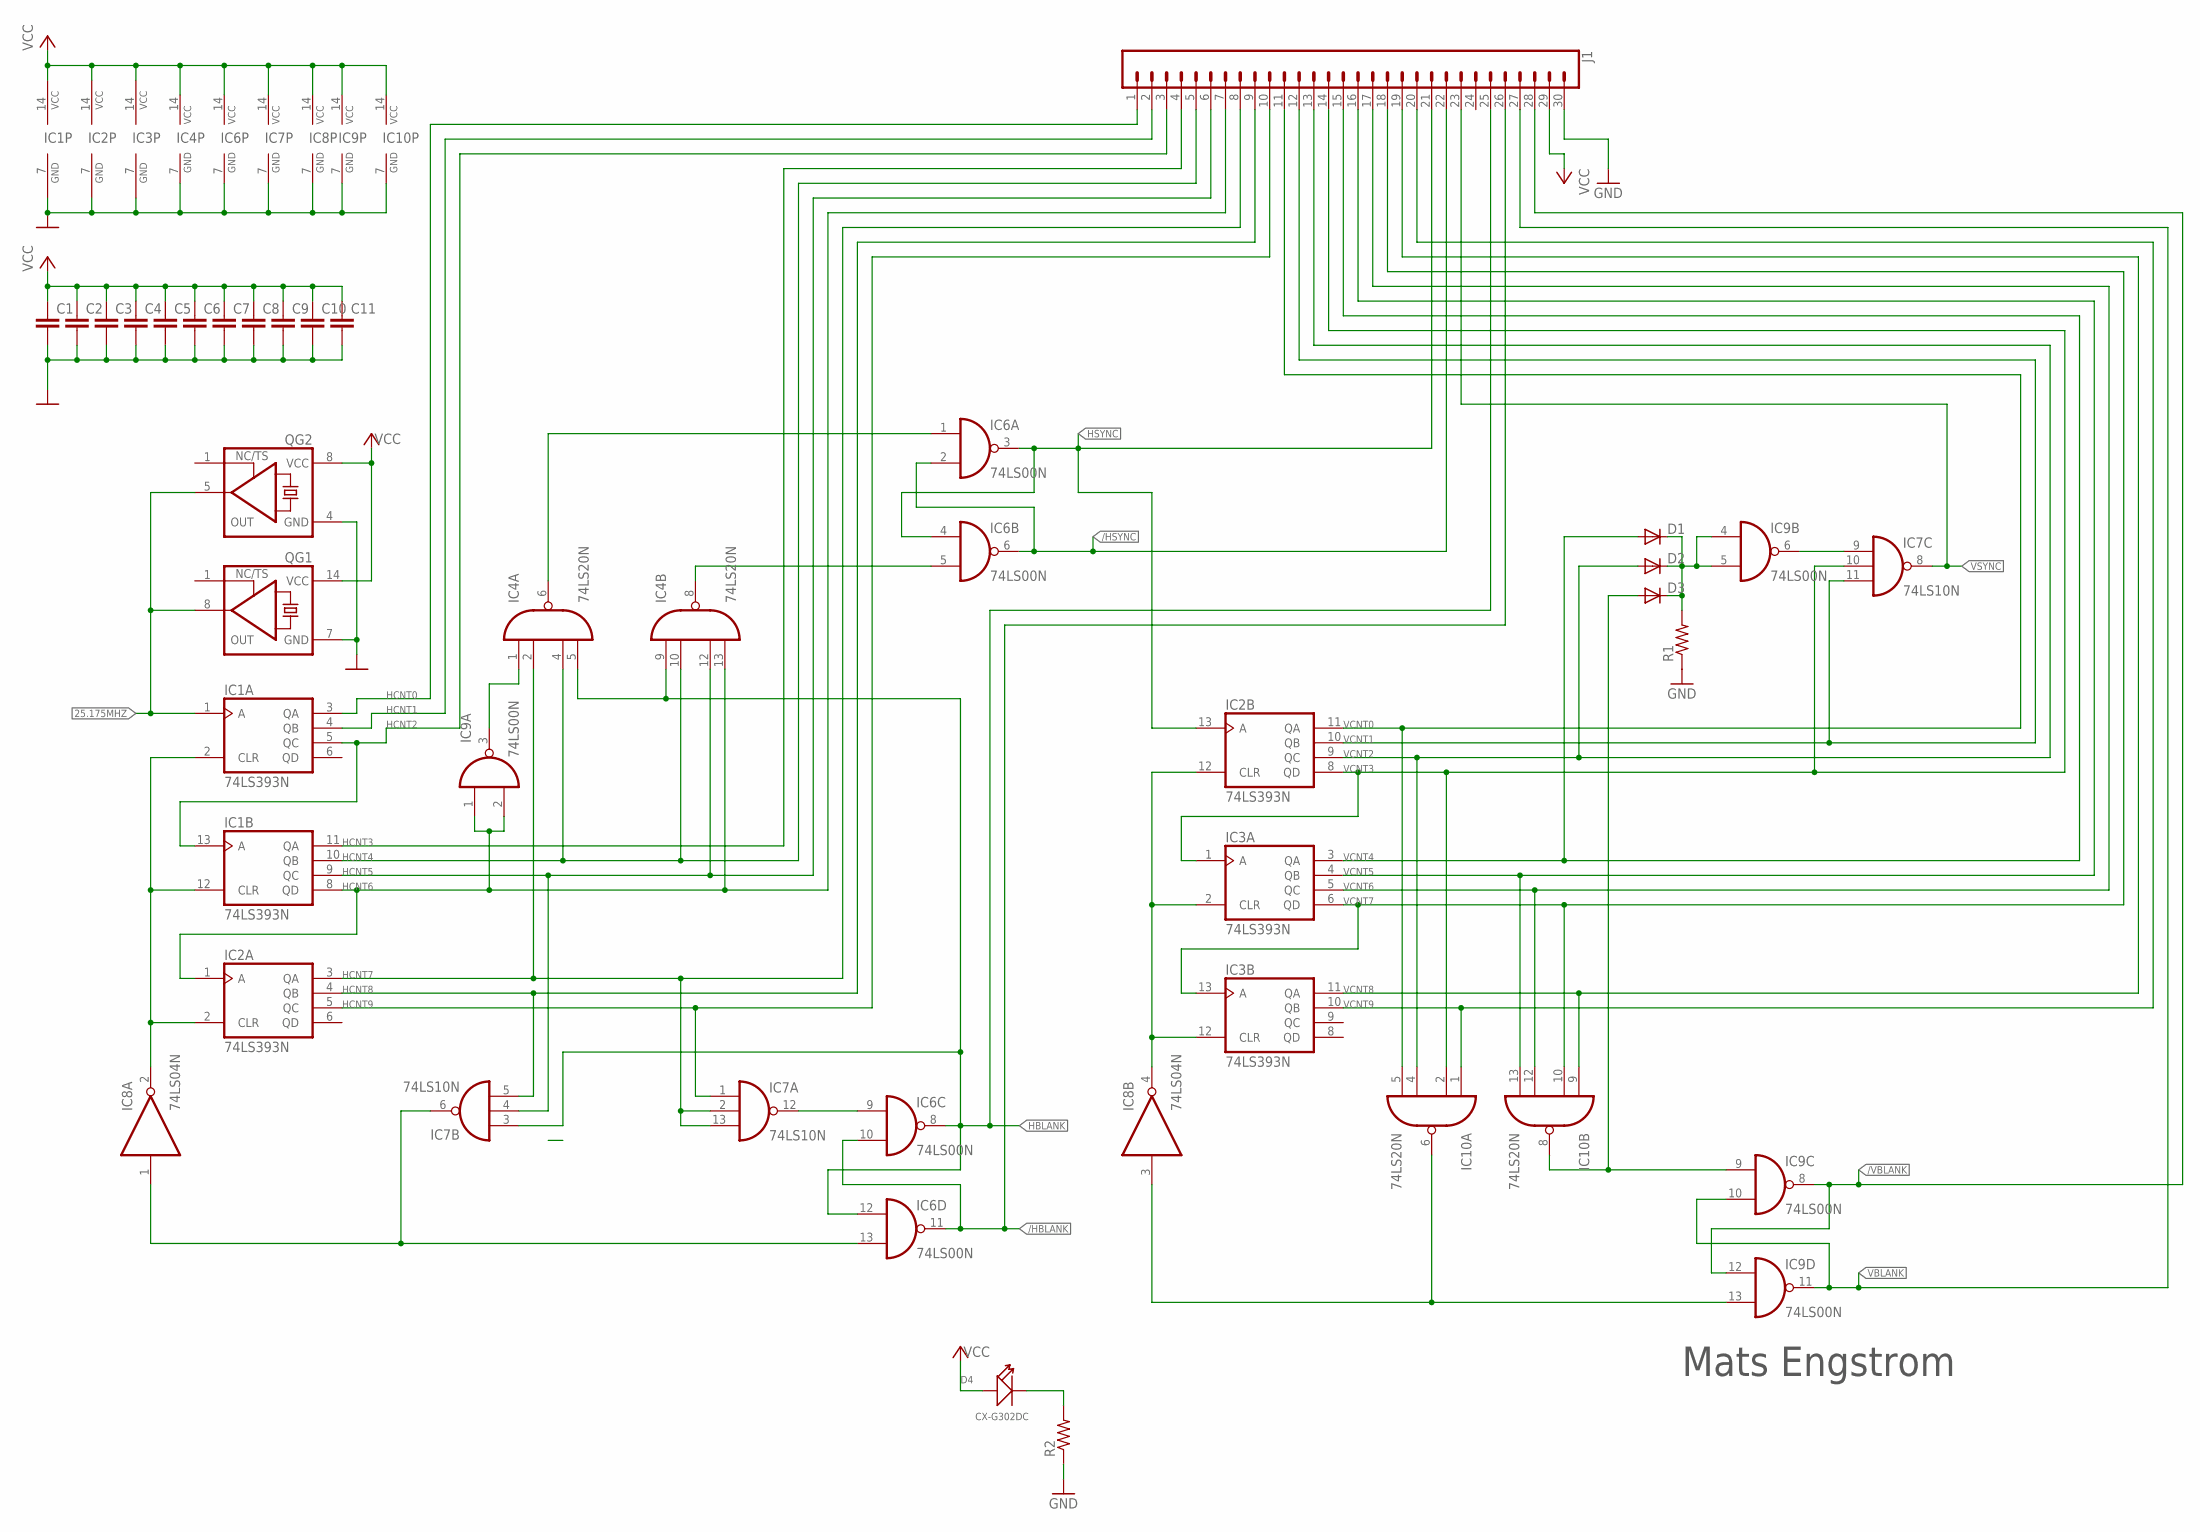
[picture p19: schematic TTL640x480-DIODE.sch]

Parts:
C1, C2, C3, C4, C5, C6, C7, C8, C9, C10, C11: C-EU050-024X044; C050-024X044
D1, D2, D3: 1N4148DO35-10; DO35-10
D4: CX-G302DC; LED2-2.54-D3.0MM
IC1, IC2, IC3: 74LS393N; DIL14
IC4, IC10: 74LS20N; DIL14
IC6, IC9: 74LS00N; DIL14
IC7: 74LS10N; DIL14
IC8: 74LS04N; DIL14
J1: CONN_30; 1X30
QG1: XO-14; DIL14S
QG2: XO-8; DIL08S
R1, R2: R-US_0204/7; 0204/7

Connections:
25.175MHZ: IC1.1 (A), QG1.8 (OUT), QG2.5 (OUT)
/HBLANK: IC6.10 (I1), IC6.11 (O), J1.26
/HSYNC: IC6.2 (I1), IC6.6 (O), J1.22
/VBLANK: IC9.8 (O), IC9.12 (I0), J1.28
GND: C1.2, C2.2, C3.2, C4.2, C5.2, C6.2, C7.2, C8.2, C9.2, C10.2, C11.2, IC1.7 (GND), IC2.7 (GND), IC3.7 (GND), IC4.7 (GND), IC6.7 (GND), IC7.7 (GND), IC8.7 (GND), IC9.7 (GND), IC10.7 (GND), J1.30, QG1.7 (GND), QG2.4 (GND), R1.1, R2.1
HBLANK: IC4.5 (I3), IC4.9 (I0), IC6.8 (O), IC6.12 (I0), IC7.3 (I0), J1.25
HCNT0: IC1.3 (QA), J1.1
HCNT1: IC1.4 (QB), J1.2
HCNT2: IC1.5 (QC), IC1.13 (A), J1.3
HCNT3: IC1.11 (QA), J1.4
HCNT4: IC1.10 (QB), IC4.4 (I2), IC4.10 (I1), J1.5
HCNT5: IC1.9 (QC), IC4.12 (I2), IC7.4 (I1), J1.6
HCNT6: IC1.8 (QD), IC2.1 (A), IC4.13 (I3), IC9.1 (I0), IC9.2 (I1), J1.7
HCNT7: IC2.3 (QA), IC4.2 (I1), IC7.2 (I1), IC7.13 (I2), J1.8
HCNT8: IC2.4 (QB), IC7.5 (I2), J1.9
HCNT9: IC2.5 (QC), IC7.1 (I0), J1.10
HSYNC: IC2.13 (A), IC6.3 (O), IC6.4 (I0), J1.21
unnamed: D1.C, D2.C, D3.C, IC9.4 (I0), IC9.5 (I1), R1.2
unnamed: IC4.1 (I0), IC9.3 (O)
unnamed: IC1.2 (CLR), IC1.12 (CLR), IC2.2 (CLR), IC8.2 (O)
unnamed: D3.A, IC9.9 (I0), IC10.8 (O)
unnamed: IC7.9 (I0), IC9.6 (O)
unnamed: IC2.12 (CLR), IC3.2 (CLR), IC3.12 (CLR), IC8.4 (O)
unnamed: IC8.3 (I), IC9.13 (I1), IC10.6 (O)
unnamed: D4.K (-), R2.2
unnamed: IC4.6 (O), IC6.1 (I0)
unnamed: IC4.8 (O), IC6.5 (I1)
unnamed: IC6.9 (I0), IC7.12 (O)
unnamed: IC6.13 (I1), IC7.6 (O), IC8.1 (I)
VBLANK: IC9.10 (I1), IC9.11 (O), J1.27
VCC: C1.1, C2.1, C3.1, C4.1, C5.1, C6.1, C7.1, C8.1, C9.1, C10.1, C11.1, D4.A (+), IC1.14 (VCC), IC2.14 (VCC), IC3.14 (VCC), IC4.14 (VCC), IC6.14 (VCC), IC7.14 (VCC), IC8.14 (VCC), IC9.14 (VCC), IC10.14 (VCC), J1.29, QG1.14 (VCC), QG2.8 (VCC)
VCNT0: IC2.11 (QA), IC10.5 (I3), J1.11
VCNT1: IC2.10 (QB), IC7.11 (I2), J1.12
VCNT2: D2.A, IC2.9 (QC), IC10.4 (I2), J1.13
VCNT3: IC2.8 (QD), IC3.1 (A), IC7.10 (I1), IC10.2 (I1), J1.14
VCNT4: D1.A, IC3.3 (QA), J1.15
VCNT5: IC3.4 (QB), IC10.13 (I3), J1.16
VCNT6: IC3.5 (QC), IC10.12 (I2), J1.17
VCNT7: IC3.6 (QD), IC3.13 (A), IC10.10 (I1), J1.18
VCNT8: IC3.11 (QA), IC10.9 (I0), J1.19
VCNT9: IC3.10 (QB), IC10.1 (I0), J1.20
VSYNC: IC7.8 (O), J1.23

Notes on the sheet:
Mats Engstrom

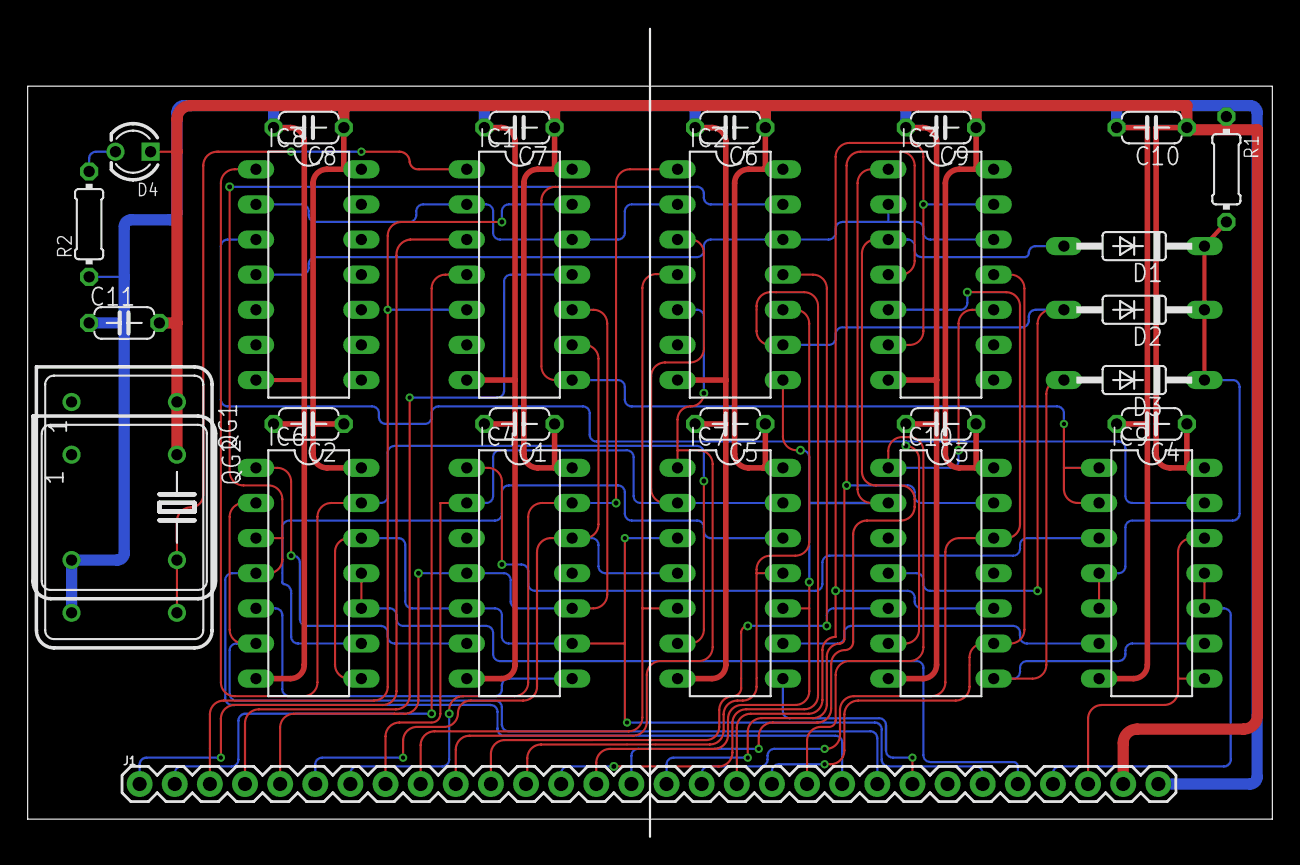
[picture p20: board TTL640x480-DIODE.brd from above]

Board: 2 copper layers, 90.0 x 53.0 mm, 29 parts (0 on the bottom side), 42 nets.

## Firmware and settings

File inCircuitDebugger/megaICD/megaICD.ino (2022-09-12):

#include <LiquidCrystal.h>

const int LCD_NB_ROWS = 2;
const int LCD_NB_COLUMNS = 16;
const int rs = 8, en = 9, d4 = 4, d5 = 5, d6 = 6, d7 = 7;
LiquidCrystal lcd(rs, en, d4, d5, d6, d7);

const int RIGHT_KEY = 1, UP_KEY = 2, DOWN_KEY = 3, LEFT_KEY = 4, SELECT_KEY = 5;

const int RWB_PIN = 38;
const int RESB_PIN = 39;
const int VPA_PIN = 40;
const int VDA_PIN = 41;
const int IRQ_PIN = 50;
const int NMI_PIN = 51;
const int ROM_W_PIN = 52;
const int BE_PIN = 53;
const int CLOCK_ENABLE_PIN = 60;
const int CLOCK_PIN = 61;

const int C1_PIN = 18;
const int C2_PIN = 19;
const int P0_PIN = 62;
const int P1_PIN = 63;
const int P2_PIN = 64;
const int P3_PIN = 65;
const int P4_PIN = 17;
const int P5_PIN = 16;
const int P6_PIN = 15;
const int P7_PIN = 14;

const int PROC_OPCODE_ADDR = 3, PROC_PROG_ADDR = 2, PROC_DATA_ADDR = 1, PROC_INTERNAL_ADDR = 0;

bool userAction = false;
bool pcActionShowed = false;
unsigned long lastPcCommand = 0;

void setup() {
  lcd.begin(LCD_NB_COLUMNS, LCD_NB_ROWS);
  lcd.clear();
  setAddressToReadState();
  setDataToReadState();
  pinMode(RWB_PIN, INPUT);
  //pinMode(RESB_PIN, INPUT);
  pinMode(RESB_PIN, OUTPUT);
  digitalWrite(RESB_PIN, LOW);
  pinMode(VPA_PIN, INPUT);
  pinMode(VDA_PIN, INPUT);
  pinMode(IRQ_PIN, INPUT);
  pinMode(NMI_PIN, INPUT);
  pinMode(ROM_W_PIN, INPUT);
  pinMode(CLOCK_ENABLE_PIN, OUTPUT);
  digitalWrite(CLOCK_ENABLE_PIN, LOW);
  pinMode(CLOCK_PIN, OUTPUT);
  digitalWrite(CLOCK_PIN, LOW);
  pinMode(BE_PIN, OUTPUT);
  digitalWrite(BE_PIN, HIGH);
  pinMode(C1_PIN, INPUT);
  pinMode(C2_PIN, INPUT);
  pinMode(P0_PIN, INPUT);
  pinMode(P1_PIN, INPUT);
  pinMode(P2_PIN, INPUT);
  pinMode(P3_PIN, INPUT);
  pinMode(P4_PIN, INPUT);
  pinMode(P5_PIN, INPUT);
  pinMode(P6_PIN, INPUT);
  pinMode(P7_PIN, INPUT);
  reset();
  Serial.begin(9600);
  lcd.write("Ready");
  lcd.setCursor(1, 3);
  lcd.write("after reset");
}

int readKeyPressed() {
  int x;
  x = analogRead(0);
  if (x < 60) {
    return RIGHT_KEY;
  }
  else if (x < 200) {
    return UP_KEY;
  }
  else if (x < 400){
    return DOWN_KEY;
  }
  else if (x < 600){
    return LEFT_KEY;
  }
  else if (x < 800){
    return SELECT_KEY;
  }
  return 0;
}

void setAddressToReadState() {
  DDRA = 0;
  DDRC = 0;
}

void setDataToReadState() {
  DDRL = 0;
}

int readAddress() {
  return (readAddressHi() << 8) + readAddressLo();
}

int readAddressHi() {
  return PINA;
}

int readAddressLo() {
  return PINC;
}

int readData() {
  return PINL;
}

void writeAddressHi(int data) {
  DDRA = 0xFF;
  PORTA = data;
}

void writeAddressLo(int data) {
  DDRC = 0xFF;
  PORTC = data;
}

void writeData(int data) {
  DDRL = 0xFF;
  PORTL = data;
}

void reset() {
  //pinMode(RESB_PIN, OUTPUT);
  digitalWrite(RESB_PIN, LOW);
  tick();
  tick();
  tick();
  tick();
  tick();
  //pinMode(RESB_PIN, INPUT);
  digitalWrite(RESB_PIN, HIGH);
}

void tick() {
  digitalWrite(CLOCK_PIN, LOW);
  digitalWrite(CLOCK_PIN, HIGH);
}

int readProcVitrualAddr() {
  return (digitalRead(VPA_PIN) << 1) + digitalRead(VDA_PIN);
}

void printData() {
  lcd.clear();
  lcd.setCursor(0, 0);
  lcd.print("Addr: ");
  lcd.setCursor(0, 1);
  lcd.print("Data: ");
  char tmp[6];
  sprintf(tmp, "%04x", readAddress());
  lcd.setCursor(6, 0);
  lcd.print(tmp);
  sprintf(tmp, "%02x", readData());
  lcd.setCursor(6, 1);
  lcd.print(tmp);
  lcd.setCursor(12, 0);
  if (digitalRead(RWB_PIN)) {
    lcd.print('R');
  } else {
    lcd.print('W');
  }
  lcd.setCursor(9, 1);
  int procVirtualAddr = readProcVitrualAddr();
  if (procVirtualAddr == PROC_OPCODE_ADDR)
    lcd.print("OPCODE ");
  else if (procVirtualAddr == PROC_PROG_ADDR)
    lcd.print("PROGRAM");
  else if (procVirtualAddr == PROC_DATA_ADDR)
    lcd.print("DATA   ");
  else
    lcd.print("INTER  ");
}

#define INVALID_COMMAND 0
#define TICK_COMMAND 1
#define BUS_STATUS_COMMAND 2
#define RESET_COMMAND 5
#define RAM_READ_COMMAND 6
#define RAM_WRITE_COMMAND 7
#define BUS_DATA_COMMAND 8
#define DONE_COMMAND 9
#define ROM_WRITE_COMMAND 10
#define DISABLE_CLOCK_COMMAND 11
#define ENABLE_CLOCK_COMMAND 12
#define CPU_BUS_ENABLE_COMMAND 13
#define CPU_BUS_DISABLE_COMMAND 14

#define RW_MASK 4
#define IRQ_MASK 8
#define NMI_MASK 0x10
#define C1_MASK 0x20
#define C2_MASK 0x40

void loop() {
  int keyPressed = readKeyPressed();
  if (keyPressed == SELECT_KEY) {
    userAction = true;
    pcActionShowed = false;
    tick();
    printData();
    delay(500);
  }
  if (keyPressed == DOWN_KEY) {
    lcd.clear();
    lcd.print("  Running at");
    lcd.setCursor(4,2);
    lcd.print("full speed");
    digitalWrite(CLOCK_PIN, LOW);
    digitalWrite(CLOCK_ENABLE_PIN, HIGH);
  }
  if (keyPressed == UP_KEY) {
    lcd.clear();
    lcd.print("Stopped and");
    lcd.setCursor(6,2);
    lcd.print("ready.");
    digitalWrite(CLOCK_PIN, LOW);
    digitalWrite(CLOCK_ENABLE_PIN, LOW);
  }
  if (keyPressed == LEFT_KEY) {
    //pinMode(RESB_PIN, OUTPUT);
    digitalWrite(RESB_PIN, LOW);
    //pinMode(RESB_PIN, INPUT);
    delay(100);
    digitalWrite(RESB_PIN, HIGH);
  }
  if (Serial.available()) {
    delay(10);
    byte commandByte = Serial.read();
    switch(commandByte) {
      case TICK_COMMAND:
        handleTickCommand();
        break;
      case RESET_COMMAND:
        handleResetCommand();
        break;
      case RAM_READ_COMMAND:
        handleRamReadCommand();
        break;
      case RAM_WRITE_COMMAND:
        handleRamWriteCommand();
        break;
      case ROM_WRITE_COMMAND:
        handleRomWriteCommand();
        break;
      case DISABLE_CLOCK_COMMAND:
        handleDisableClockCommand();
        break;
      case ENABLE_CLOCK_COMMAND:
        handleEnableClockCommand();
        break;
      case CPU_BUS_ENABLE_COMMAND:
        handleEnableCpuBusCommand();
        break;
      case CPU_BUS_DISABLE_COMMAND:
        handleDisableCpuBusCommand();
        break;
    }
    userAction = false;
    lastPcCommand = millis();
  }
  updateDisplay();
}

void updateDisplay() {
  if (userAction) return;
  if (lastPcCommand == 0) return; 
  if (pcActionShowed) {
    if (lastPcCommand + 1000 < millis()) {
      lcd.clear();
      lcd.write("Ready");
      pcActionShowed = false;
    }
  } else {
    if (lastPcCommand + 1000 > millis()) {
      lcd.clear();
      lcd.write("PC commands");
      lcd.setCursor(1, 7);
      lcd.write("processing...");
      pcActionShowed = true;
    }
  }
}

void handleTickCommand() {
  do {
    tick();
  } while (readProcVitrualAddr() == 0);
  reportBusStatus();
}

void reportBusStatus() {
  Serial.write(BUS_STATUS_COMMAND);
  Serial.write(readAddressHi());
  Serial.write(readAddressLo());
  Serial.write(readData());

  int port = digitalRead(P7_PIN);
  port = (port << 1) + digitalRead(P6_PIN);
  port = (port << 1) + digitalRead(P5_PIN);
  port = (port << 1) + digitalRead(P4_PIN);
  port = (port << 1) + digitalRead(P3_PIN);
  port = (port << 1) + digitalRead(P2_PIN);
  port = (port << 1) + digitalRead(P1_PIN);
  port = (port << 1) + digitalRead(P0_PIN);

  Serial.write(port);
  
  int flags = readProcVitrualAddr();
  if (digitalRead(RWB_PIN))
    flags |= RW_MASK;
  if (digitalRead(IRQ_PIN))
    flags |= IRQ_MASK;
  if (digitalRead(NMI_PIN))
    flags |= NMI_MASK;
  if (digitalRead(C1_PIN))
    flags |= C1_MASK;
  if (digitalRead(C2_PIN))
    flags |= C2_MASK;
  Serial.write(flags);
}

void handleResetCommand() {
  reset();
  Serial.write(DONE_COMMAND);
}

void handleRamReadCommand() {
  digitalWrite(CLOCK_PIN, LOW);
  writeAddressHi(Serial.read());
  writeAddressLo(Serial.read());
  pinMode(RWB_PIN, OUTPUT);
  digitalWrite(RWB_PIN, HIGH);
  digitalWrite(CLOCK_PIN, HIGH);
  int data = readData();
  digitalWrite(CLOCK_PIN, LOW);
  pinMode(RWB_PIN, INPUT);
  setAddressToReadState();
  Serial.write(BUS_DATA_COMMAND);
  Serial.write(data);
}

void handleRamWriteCommand() {
  digitalWrite(CLOCK_PIN, LOW);
  writeAddressHi(Serial.read());
  writeAddressLo(Serial.read());
  writeData(Serial.read());
  pinMode(RWB_PIN, OUTPUT);
  digitalWrite(RWB_PIN, LOW);
  digitalWrite(CLOCK_PIN, HIGH);
  digitalWrite(CLOCK_PIN, LOW);
  pinMode(RWB_PIN, INPUT);
  setAddressToReadState();
  setDataToReadState();
  Serial.write(DONE_COMMAND);
}

void handleRomWriteCommand() {
  digitalWrite(CLOCK_PIN, LOW);
  pinMode(ROM_W_PIN, OUTPUT);
  digitalWrite(ROM_W_PIN, LOW);
  writeAddressHi(Serial.read());
  writeAddressLo(Serial.read());
  writeData(Serial.read());
  digitalWrite(CLOCK_PIN, HIGH);
  digitalWrite(CLOCK_PIN, LOW);
  pinMode(ROM_W_PIN, INPUT);
  setAddressToReadState();
  setDataToReadState();
  Serial.write(DONE_COMMAND);
}

void handleDisableClockCommand() {
  digitalWrite(CLOCK_ENABLE_PIN, LOW);
  Serial.write(DONE_COMMAND);
}

void handleEnableClockCommand() {
  digitalWrite(CLOCK_PIN, LOW);
  digitalWrite(CLOCK_ENABLE_PIN, HIGH);
  Serial.write(DONE_COMMAND);
}

void handleEnableCpuBusCommand() {
  digitalWrite(BE_PIN, HIGH);
  Serial.write(DONE_COMMAND);
}

void handleDisableCpuBusCommand() {
  digitalWrite(BE_PIN, LOW);
  Serial.write(DONE_COMMAND);
}

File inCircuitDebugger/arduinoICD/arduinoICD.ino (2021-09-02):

#define OE_ADDR_PIN 11
#define OE_DATA_PIN 4
#define S0_ADDR_PIN 10
#define S0_DATA_PIN 3
#define S1_ADDR_PIN 7
#define S1_DATA_PIN 6
#define SHIFT_CLOCK_PIN 9
#define Q_ADDR_PIN 12
#define Q_DATA_PIN 5
#define DS_SHIFT_PIN 8
#define CPU_CLOCK_PIN 13
#define RW_PIN 18
#define RESET_PIN 19
#define VPA_PIN 20
#define VDA_PIN 21
#define ROM_RW_PIN 14
#define CPU_BUS_ENABLE_PIN 15

#define RESET_TICK_COUNT 6

class ShiftReg {
  public:
    ShiftReg(byte oePin, byte s0Pin, byte s1Pin, byte clockPin, byte qPin, byte dsPin, byte size);
    void write(int data);
    int read();
    inline void outputDisable() __attribute__((always_inline));
  private:
    byte _oePin;
    byte _s0Pin;
    byte _s1Pin;
    byte _clockPin;
    byte _qPin;
    byte _dsPin;
    byte _size;
    inline void outputEnable() __attribute__((always_inline));
    inline void tick() __attribute__((always_inline));
    inline void shiftEnable() __attribute__((always_inline));
    inline void hold() __attribute__((always_inline));
    inline void parallelLoad() __attribute__((always_inline));
};

ShiftReg::ShiftReg(byte oePin, byte s0Pin, byte s1Pin, byte clockPin, byte qPin, byte dsPin, byte size) {
  pinMode(oePin, OUTPUT);
  digitalWrite(oePin, HIGH);
  _oePin = oePin;
  pinMode(s0Pin, OUTPUT);
  digitalWrite(s0Pin, LOW);
  _s0Pin = s0Pin;
  pinMode(s1Pin, OUTPUT);
  digitalWrite(s1Pin, LOW);
  _s1Pin = s1Pin;
  pinMode(clockPin, OUTPUT);
  digitalWrite(clockPin, LOW);
  _clockPin = clockPin;
  pinMode(qPin, INPUT);
  _qPin = qPin;
  pinMode(dsPin, OUTPUT);
  digitalWrite(dsPin, LOW);
  _dsPin = dsPin;
  _size = size;
};

void ShiftReg::outputEnable() {
  digitalWrite(_oePin, LOW);
}

void ShiftReg::outputDisable() {
  digitalWrite(_oePin, HIGH);
}

void ShiftReg::tick() {
  //digitalWrite(_clockPin, HIGH);

  PORTB |= B00100000;
  //digitalWrite(_clockPin, LOW); 
  PORTB &= B11011111;
}

void ShiftReg::shiftEnable() {
  digitalWrite(_s0Pin, LOW);
  digitalWrite(_s1Pin, HIGH);
}

void ShiftReg::hold() {
  digitalWrite(_s0Pin, LOW);
  digitalWrite(_s1Pin, LOW);
}

void ShiftReg::parallelLoad() {
  digitalWrite(_s0Pin, HIGH);
  digitalWrite(_s1Pin, HIGH);
}

void ShiftReg::write(int data) {
  shiftEnable();
  for (byte i = 0; i < _size; i++) {
    digitalWrite(_dsPin, data & 1);
    tick();
    data = data >> 1;
  }
  hold();
  outputEnable();
}

int ShiftReg::read() {
  outputDisable();
  parallelLoad();
  tick();
  shiftEnable();
  int pos = 1;
  int result = 0;
  for (byte i = 0; i < _size; i++) {
    if (digitalRead(_qPin))
      result += pos;
    pos = pos << 1;
    tick();
  }
  hold();
  return result;
}

ShiftReg addrReg(OE_ADDR_PIN, S0_ADDR_PIN, S1_ADDR_PIN, SHIFT_CLOCK_PIN, Q_ADDR_PIN, DS_SHIFT_PIN, 16);
ShiftReg dataReg(OE_DATA_PIN, S0_DATA_PIN, S1_DATA_PIN, SHIFT_CLOCK_PIN, Q_DATA_PIN, DS_SHIFT_PIN, 8);

void setup() {
  pinMode(CPU_CLOCK_PIN, OUTPUT);
  digitalWrite(CPU_CLOCK_PIN, LOW);
  pinMode(RW_PIN, INPUT);
  pinMode(RESET_PIN, INPUT);
  pinMode(VPA_PIN, INPUT);
  pinMode(VDA_PIN, INPUT);
  pinMode(ROM_RW_PIN, INPUT);
  pinMode(CPU_BUS_ENABLE_PIN, OUTPUT);
  digitalWrite(CPU_BUS_ENABLE_PIN, LOW);
  Serial.begin(9600);
}

#define INVALID_COMMAND 0
#define TICK_COMMAND 1
#define DATA_WRITE_COMMAND 2
#define CPU_READ_COMMAND 3
#define CPU_WRITE_COMMAND 4
#define RESET_COMMAND 5
#define RAM_READ_COMMAND 6
#define RAM_WRITE_COMMAND 7
#define BUS_DATA_COMMAND 8
#define DONE_COMMAND 9
#define ROM_WRITE_COMMAND 10
#define DISABLE_CLOCK_COMMAND 11
#define ENABLE_CLOCK_COMMAND 12
#define CPU_BUS_ENABLE_COMMAND 13
#define CPU_BUS_DISABLE_COMMAND 14

#define VPA_COMMAND_FLAG 0x80
#define VDA_COMMAND_FLAG 0x40

#define VPA_COMMAND_FLAG_OFFSET 7
#define VDA_COMMAND_FLAG_OFFSET 7

void loop() {
  if (Serial.available()) {
    byte commandByte = Serial.read();
    switch(commandByte) {
      case TICK_COMMAND:
        tickCPUCommand();
        break;
      case DATA_WRITE_COMMAND:
        handleDataWriteCommand();
        break;
      case RESET_COMMAND:
        handleResetCommand();
        break;
      case RAM_READ_COMMAND:
        handleRamReadCommand();
        break;
      case RAM_WRITE_COMMAND:
        handleRamWriteCommand();
        break;
      case ROM_WRITE_COMMAND:
        handleRomWriteCommand();
        break;
      case DISABLE_CLOCK_COMMAND:
        handleDisableClockCommand();
        break;
      case ENABLE_CLOCK_COMMAND:
        handleEnableClockCommand();
        break;
      case CPU_BUS_ENABLE_COMMAND:
        handleEnableCpuBusCommand();
        break;
      case CPU_BUS_DISABLE_COMMAND:
        handleDisableCpuBusCommand();
        break;
    }
  }
}

byte commandToWrite[4];

void tickCPUCommand() {
  byte vpa;
  byte vda;
  do {
    tickCPU();
    vpa = digitalRead(VPA_PIN);
    vda = digitalRead(VDA_PIN);
  } while (vpa + vda == 0);
  int addr = addrReg.read();
  byte rw = digitalRead(RW_PIN);
  if (rw == 0) {
    int data = dataReg.read();
    commandToWrite[0] = CPU_WRITE_COMMAND + vpa * VPA_COMMAND_FLAG + vda * VDA_COMMAND_FLAG;
    commandToWrite[1] = (addr >> 8) & 0xFF;
    commandToWrite[2] = addr & 0xFF;
    commandToWrite[3] = data;
    Serial.write(commandToWrite, 4);
  } else {
    commandToWrite[0] = CPU_READ_COMMAND + vpa * VPA_COMMAND_FLAG + vda * VDA_COMMAND_FLAG;
    commandToWrite[1] = (addr >> 8) & 0xFF;
    commandToWrite[2] = addr & 0xFF;
    Serial.write(commandToWrite, 3);
  }
}

void handleDataWriteCommand() {
  byte data = -1;
  do {
    data = Serial.read();
  } while (data == -1);
  dataReg.write(data);
  tickCPUCommand();
}

void handleResetCommand() {
  pinMode(RESET_PIN, OUTPUT);
  digitalWrite(RESET_PIN, LOW);
  for (int i = 0; i <= RESET_TICK_COUNT; i++)
    tickCPU();
  pinMode(RESET_PIN, INPUT);
  // tickCPUCommand();
}

void tickCPU() {
  digitalWrite(CPU_CLOCK_PIN, LOW);
  dataReg.outputDisable();
  digitalWrite(CPU_CLOCK_PIN, HIGH);
}

void handleRamReadCommand() {
  int addr = (Serial.read() << 8) + Serial.read();
  digitalWrite(CPU_CLOCK_PIN, LOW);
  pinMode(RW_PIN, OUTPUT);
  digitalWrite(RW_PIN, HIGH);
  addrReg.write(addr);
  digitalWrite(CPU_CLOCK_PIN, HIGH);
  int data = dataReg.read();
  digitalWrite(CPU_CLOCK_PIN, LOW);
  commandToWrite[0] = BUS_DATA_COMMAND;
  commandToWrite[1] = data;
  pinMode(RW_PIN, INPUT);
  addrReg.outputDisable();
  Serial.write(commandToWrite, 2);
}

void handleRamWriteCommand() {
  int addr = (Serial.read() << 8) + Serial.read();
  int data = Serial.read();
  digitalWrite(CPU_CLOCK_PIN, LOW);
  pinMode(RW_PIN, OUTPUT);
  digitalWrite(RW_PIN, LOW);
  addrReg.write(addr);
  dataReg.write(data);
  digitalWrite(CPU_CLOCK_PIN, HIGH);
  digitalWrite(CPU_CLOCK_PIN, LOW);
  commandToWrite[0] = DONE_COMMAND;
  pinMode(RW_PIN, INPUT);
  addrReg.outputDisable();
  dataReg.outputDisable();
  Serial.write(commandToWrite, 1);
}
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

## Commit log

2021-02-20 Couple tests
2021-03-07 CPU board initial
    [cpuBoard.kicad_pcb, cpuBoard.sch]
2021-04-03 Rewrite arduino part
2021-04-10 Try to speed up arduino
2021-04-10 Keyboard first try
    [keyboard_board.kicad_pcb, keyboard_board.sch]
2021-05-12 Second version of in circuit debugger
2021-06-10 Added schemas for arduino & lcd screen
    [arduino.kicad_pcb, arduino.sch, lcdScreen.kicad_pcb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]
2021-06-24 Start second version of hardware
    [RAM.kicad_pcb, RAM.sch, ROM.kicad_pcb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]
2021-07-31 ROM changes
    [ROM.sch]
2021-09-02 Another random commit
    [PS2.kicad_pcb, PS2.sch]
2021-11-15 Some updtades
    [cpuBoard.kicad_pcb, cpuBoard.sch]
2021-11-20 Updated mega Arduino things
    [cpuBoard.sch]
2021-12-08 Debug clock
    [cpuBoard.sch]
2022-09-12 esc & enter
2022-09-13 Fix enter changing line
    [display.asm]
2022-09-15 UART software echo
2022-09-15 Add UART board
    [VIA_22_board.kicad_sch, uart.kicad_pcb, uart.kicad_sch]
2022-09-22 Board changes
    [VIA_22_2.kicad_pcb, VIA_22_2.kicad_sch, VIA_22_2.sch]
2022-10-02 UART ping works
2022-10-02 Read is implemented but not works
    [main.asm]
2022-10-02 Test for UART
2022-10-02 uart works in ROM
2022-10-09 Update IRQ vector after UART run programm
2022-10-30 uart6502 can be installed locally
2022-10-30 uart6502 can read & output raw data
2022-10-30 uart6502 change default write file
2022-10-30 uart6502 working with multiple pages
2022-10-30 uart6502 looks good
2023-02-19 uart6502 show logs
2023-02-19 uart6502 compile and run ability
2023-02-19 uart6502 flush each char
2023-04-09 Debug printing
2023-09-08 Type when I run in via uart
2023-10-08 working cc65 simple code
    [uartMon.cfg]
2024-01-27 Rewriting uart test
2024-02-11 SD refactoring for good clock duty cycle
    There is a floating bag. Mabye with UART output.
2024-02-19 VIA 2 schematcs
    [VIA_22_2.kicad_sch]
2024-03-13 Fix file not found
    [fat.asm]
2024-05-26 Update uart6502
    It don't show stacktrace that often.
    Non printable characters printed in hex.
2024-06-01 Calc running time for uart6502
2024-07-03 Folder renaming
    [uartMon.cfg]
2024-07-05 Shematics refactoring
    [PS2.kicad_pcb, PS2.sch, RAM.kicad_pcb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]
2024-07-05 Fix errors in schematics
    [arduinoNanoConnector.kicad_sch, charDisplayAdapter.kicad_sch, cpu.kicad_sch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]
2024-07-05 Update sd adapter schematic
    [sdShift.kicad_sch]
2024-07-20 SD shift based on interrupt
2024-07-24 Preparing for Forth programming
    Stripper for clean Forth of comment, newlines, etc.
    Check for numbers in order to fail on unknown words.
    Bring debug flags in one place.
    [classic.asm]
2024-07-31 Fix stripper and implementing if
    [classic.asm]
2024-08-04 LOOP works
    As well as I and LEAVE.
    FIX NAN logic.
    [classic.asm]
2024-10-27 Differentiate interrupts
2024-10-28 Try to use 6522 timer
2024-11-17 uart6502 v0.6.0
    Allow to connect via network
2024-11-30 Update shematics for UART & ESP
    [esp.kicad_sch, markus.kicad_sch, uart.kicad_sch]
2024-12-03 Fix interrupt handler for the timer
    [classic.asm]
2024-12-15 Native FORTH prints invitation
2024-12-17 Renaming to Marcus
    [arduinoNanoConnector.kicad_sch, charDisplayAdapter.kicad_sch, cpu.kicad_sch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]
2024-12-19 Set longer timeout
    But it didn't help
    [main.cpp]
2025-01-26 Add UART and CharDisplay libs
2025-01-30 Update Arduino python script
    For dump whole ROM.
2025-01-30 EEPROM writer
    Now I can update EEPROM without Arduino
2025-02-01 Update ROM design
    [arduinoNanoConnector.kicad_sch, cpu.kicad_sch, ps2adapter.kicad_sch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]
2025-02-09 Add 3D model
    [bus.scad, common.scad, cpu.scad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]
2025-02-10 Speed up UART
2025-02-11 uart6502 supports atari files
2025-02-12 Update uart6502 compile&run
2025-03-03 Steps toward UART
2025-03-07 Fix spurious interrupts
2025-03-08 FORTH via UART
2025-03-12 Send file to UART
2025-03-17 FORTH convert UART to upper case
2025-03-18 Reset UART
2025-03-19 Fix uart6502 script sending
2025-03-21 uart6502 several script files
2025-03-22 FORTH fix stack check
    delete auto upper case
    enable interrupts after variables are prepared
2025-03-22 uart6502 send script fix
    Wait for 6502 invitation before sending script content
2025-03-22 FORTH fix comment cut
2025-07-03 Update schematics for latest KiCad
    [arduinoNanoConnector.kicad_sch, charDisplayAdapter.kicad_sch, cpu.kicad_sch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]
2025-07-21 Update schematics for peripherals
    [marcus.kicad_sch, peripherals.kicad_sch, sdShift.kicad_sch]
2025-07-23 Update schematics pin numbers
    [peripherals.kicad_sch, ps2adapter.kicad_sch]
2025-07-26 Update schematics with audio amplifier
    [peripherals.kicad_sch]
2025-09-02 Update UART schematics for flow control
    [uart.kicad_sch]
2025-09-16 new UART support
    fix schematics by adding a resistor
    renaming PC/2 to correct PS/2
    Updating FORTH to detect terminal connection
    [peripherals.kicad_sch, uart.kicad_sch]
2025-09-30 Display & keyboard from peripherals board
    As well as fixing wrong soldering.
2025-10-21 Fix UART pullup
    [uart.kicad_sch]
2025-10-22 Fix UART monitor to work with data carrier pin
2026-02-07 Fixed uart monitor interrup and stack
2026-02-08 uart6502 fix
    Update opcodes. Fix args parsing.
2026-02-14 [ADR] 0009 same uart6502 for Arduio
2026-02-14 [ADR] 0010 Disable Arduino autoreboot
2026-02-14 [ADR] 0011 autodetect peripherals
    [peripherals.kicad_sch]
2026-06-05 Add resistor to clock in peripherals board
    [arduinoNanoConnector.kicad_sch, charDisplayAdapter.kicad_sch, cpu.kicad_sch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]
2026-06-05 Some tweaks for UART Flow control
    It works, but not reliably. I'd rather delete it.
2026-06-05 Reprint schematics
2026-06-05 Add ADR-0012 UART backpressure
2026-06-05 Add ADR-0013 UART interrupt
2026-06-11 Draw reset board
    [marcus.kicad_sch, reset.kicad_sch]
2026-06-12 Add TTL VGA schematics
    [TTL640x480-DIODE.brd, TTL640x480-DIODE.kicad_sch, TTL640x480-DIODE.sch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]
2026-06-18 Print date
2026-06-23 Fix uart6502 type command
2026-07-13 Printing stack in tests
2026-07-13 Tetris implementation
    Block falling
    Check field boundaries
    Next block after the current stopped
2026-07-16 Fix FORTH UART connection
2026-08-21 Add VGA to VIA board
    [VGA_TO_VIA.kicad_pcb, VGA_TO_VIA.kicad_sch]
2026-09-15 Update VGA to VIA delay line
    [VGA_TO_VIA.kicad_sch]
2026-09-23 Update VGA to VIA
    [VGA_TO_VIA.kicad_sch]

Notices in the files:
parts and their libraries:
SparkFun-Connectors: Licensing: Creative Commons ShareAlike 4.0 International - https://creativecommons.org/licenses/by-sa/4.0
